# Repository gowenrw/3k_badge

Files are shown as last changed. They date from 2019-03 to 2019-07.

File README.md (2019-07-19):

# 3k_badge

3000 Society Badge Documents

## File Structure

This is the file structure of this repository

* 3k_badge_eda - Electronic Design Automation files for the badge PCB (EDA is KiCad)
  * 3000_Society_Badge_K5 - KiCad 5.x project folder for the 3000 Society Conference version of the badge
  * DC27_3000_Society_Badge_K5 - KiCad 5.x project folder for the Defcon 27 Conference version of the badge
* code - Code for programming the badge
  * 3kcode - Current python code for trinket m0 controlling the bage
* docs - Documentation created by this project related to the badge
* graphics - Artwork and other graphics created by this project for the badge
  * fonts - Truetype fonts used in the Illustrator files
* reference - Documentation pulled from other sources related to the badge components

## Badge Details

Details on the badge can be found on the website https://3kbadge.altbier.us/

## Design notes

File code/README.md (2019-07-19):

# code

Code for programming the badge

The trinket m0 can run multiple versions of Circuit Python and may come shipped with different versions loaded.

For consistency in code and deployment I have standardized on Circuit Python version 2.3.1

The trinket m0 firmware for the version we are using has been included here in file adafruit-circuitpython-trinket_m0-2.3.1.uf2

To upgrade or downgrade the trinket m0 to run Circuit Python version 2.3.1 follow these steps.

* Connect the trinket m0 to a PC via the USB port.
  * This should pop open a USB drive called CIRCUITPY that is used for adding code
* Click the small Reset button on the trinket twice.  Not like a mouse Double-click, but more like Click-pause-Click.
  * You should see the Dotstar RGB LED turn green and the Red LED turn on and a new disk drive appear called TRINKETBOOT.
* Drag the adafruit-circuitpython-trinket_m0-2.3.1.uf2 firmware file to TRINKETBOOT to copy it there.
  * The Red LED will flash then the TRINKETBOOT drive will disappear and the CIRCUITPY drive will reappear.
* That's it, the trinket is now running the new firmware for Circuit Python version 2.3.1

More information about the trinket m0 and Circuit Python can be found here https://learn.adafruit.com/adafruit-trinket-m0-circuitpython-arduino/circuitpython

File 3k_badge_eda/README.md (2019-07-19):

# 3k_badge_eda

Electronic Design Automation files for the badge PCB (EDA is KiCad)

* 3000_Society_Badge_K5 - KiCad 5.x project folder for the 3000 Society Conference version of the badge
* DC27_3000_Society_Badge_K5 - KiCad 5.x project folder for the Defcon 27 Conference version of the badge

Shitty Addon (SAO) KiCad files downloaded from here:
https://hackaday.io/project/52950-shitty-add-ons

I ended up not doing the SAO connector as planned due to time constraints.

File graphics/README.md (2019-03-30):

# graphics

Artwork and other graphics created by this project for the badge

I used Adobe Illustrator to create the vector graphics that are to be exported to KiCad.

I have included the special fonts I used in these graphics files in case they are needed to properly edit them.
These fonts are in a fonts subdirectory here.

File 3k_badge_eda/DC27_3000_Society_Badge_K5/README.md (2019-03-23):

# 3000_Society_Badge_K5

This directory contains the KiCad version 5.x project files for the 3000 Society Badge.

Here is the layout of the project directory:
* ./ - The root directory contains the main KiCad files for the project
  * <filename>.pro: project file. Holds parameters that apply to the entire project (schematic and PCB layout).
  * <filename>.sch: schematic file.
  * <filename>.kicad_pcb: the new PCB layout file.
  * <filename>.net: netlist in "Pcbnew" format
  * <filename>.bak: backup of schematic file.
  * <filename>.kicad_pcb-bak: backup of the new PCB layout file.
  * <filename>-cache.lib: a local cache copy of all the symbols used in the schematic
  * fp-lib-table: Footprint library list
  * sym-lib-table: Schematic library list
* ./lib_sh - This directory contains schematic library files
  * <filename>.lib: schematic symbols library file.
* ./lib_fp - This directory contains footprint module directories
  * <dirname>.pretty: footprint module directory
    * <filename>.mod: footprint module file
* ./3d_models - This directory contains footprint 3d model files
  * <filename>.wrl: VRML 3D model used in the 3D viewer to represent parts.
* ./gerber - This directory contains gerber formatted files for manufacturing

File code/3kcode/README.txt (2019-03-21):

Welcome to CircuitPython!
#############################

Visit the Trinket M0 product page here for more info:
                              https://adafruit.com/product/3500

#############################

The Trinket has a very tiny disk drive so we have disabled Mac OS X indexing
which could take up that valuable space.

So *please* do not remove the empty .fseventsd/no_log, .metadata_never_index
or .Trashes files!

#############################

The pre-loaded demo shows off what your Trinket M0 can do with CircuitPython:
  * The built in DotStar LED can show any color, it will swirl through the rainbow
  * Pin D0 is an analog input, the REPL will display the voltage on this pin
    (0-3.3V is the max range)
  * Pin D1 is a true analog output, you will see the voltage slowly rise
  * Pin D2 is a digital input with a pull-up, you can touch this pad to GND
    to activate the button (or wire up a tactile button or switch!)
    If you update main.py to uncomment the relevant lines, it will act as a
    mini keyboard and emulate an 'a' key-press whenever D2 is grounded.
  * Pin D3 is a capacitive input, when touched, it will turn on the red LED.
  * Pin D4 is a NeoPixel output, you can wire up a strip of NeoPixels to this
    pin (power from USB and GND). The first 16 NeoPixel will rainbow swirl

For more details on how to use CircuitPython, visit
https://adafruit.com/product/3500 and check out all the tutorials we have!

#############################
CircuitPython Quick Start:

Changing the code is as easy as editing main.py in your favorite text editor.
We recommend Atom, Notepad++, or Visual Studio Code. After the file is saved,
CircuitPython will automatically reload the latest code. Try enabling the
single-button keyboard (HINT: look for the "# optional! uncomment below..." text)

Connecting to the serial port will give you access to better error messages and
interactive CircuitPython (known as the REPL). On Windows we recommend Tera Term
or PuTTY. On Mac OSX and Linux, 'screen' can be used from a terminal.

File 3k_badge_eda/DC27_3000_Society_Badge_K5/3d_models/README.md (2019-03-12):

# 3d_models

This directory is for .STEP and .WRL model files for all footprints

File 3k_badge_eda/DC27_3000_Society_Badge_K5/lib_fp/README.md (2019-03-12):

# lib_fp

This directory is for footprints

This local library contains footprints for the components used as well as the silkscreen art.

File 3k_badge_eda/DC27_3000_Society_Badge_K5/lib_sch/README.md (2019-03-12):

# lib_sch

This directory is for schematic symbols

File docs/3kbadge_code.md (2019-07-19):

# Godzilla vs. Blade Runner Badge Code

[HOME](/) - [DETAILS](3kbadge_details.md) - [PARTS](3kbadge_components.md) - [ASSEMBLY](3kbadge_assembly.md) - [CODE](3kbadge_code.md) - [I WANT ONE!](3kbadge_i_want_one.md)

This is where you will find detailed step by step instructions on how to update the firmware and add or change code on the trinket m0 that controls the badge.

If you received your trinket m0 as part of a badge kit or with your badge then the firmware is already at the proper version and it will already have working badge code on it.
So, you need to do nothing unless you want to change the code (see modifying code section below)

If you have sourced your own trinket m0 for a PCB only badge then you will need to update the firmware to a version that has been tested to work with our badge code unless you are planning to write your own code for it.

## Get Your Trinket M0 To Work With Our Badge

The code that runs the badge was written in CircuitPython version 2.3.1 and has been tested to work on most 2.x CircuitPython firmware versions.  
It is also known that this code does not work (for some reason that we have not had time to troubleshoot) on the CircuitPython 3.x or 4.x versions that are shipping with Trinkets now.

### Updating the CircuitPython Firmware

To update the firmware is a fairly simple process.

* Connect the trinket m0 to a PC via the USB port.
  * This should pop open a USB drive called CIRCUITPY that is used for adding code
* Click the small Reset button on the trinket twice.  Not like a mouse Double-click, but more like Click-pause-Click.
  * You should see the Dotstar RGB LED turn green and the Red LED turn on and a new disk drive appear called TRINKETBOOT.
* Drag the .uf2 extension firmware file (e.g. adafruit-circuitpython-trinket_m0-2.3.1.uf2) to TRINKETBOOT to copy it there.
  * The Red LED will flash then the TRINKETBOOT drive will disappear and the CIRCUITPY drive will reappear.
* That's it, the trinket is now running the new firmware for the Circuit Python version that you copied to it.

### Updating the CircuitPython Libraries and Code

The library files and code used are firmware version dependent.  So, if you update the firmware you need to make sure that you also update any libraries and code used to that specific firmware version.
This is very easy to do.

* Connect the trinket m0 to a PC via the USB port.
  * This should pop open a USB drive called CIRCUITPY that is used for adding code
* You will see a main.py file which contains the code and a lib directory that contains the libraries
* Copy your new code and library files to this drive overwriting the existing files.
  * This is the same process you would use on any USB drive
* That's it, the trinket should start running the new code and libraries immediately.
  * If for some reason it does not simply press the Reset button once

### Using the Firmware, Libraries and Code Provided Here

If you are going to install the badge code that has been provided here then you can use the firmware and library files that have also been provided here.

* The 2.3.1 firmware is in this GitHub repositories [code directory](https://GitHub.com/gowenrw/3k_badge/tree/master/code).
* The main.py file which contains all the code for the badge in this GitHub repositories [code/3kcode directory](https://GitHub.com/gowenrw/3k_badge/tree/master/code/3kcode).
* The 2.3.1 library files used by the code are in this GitHub repositories [code/3kcode/lib directory](https://GitHub.com/gowenrw/3k_badge/tree/master/code/3kcode/lib).

### Using the Firmware and Libraries provided by Adafruit CircuitPython

If you are going to write your own badge code and use a different version of CircuitPython than what has been provided then you will need to download the Firmware and Libraries from Adafruit CircuitPython.

Find the CircuitPython firmware release you wish to use from the [Adafruit GitHub CircuitPython releases repository](https://GitHub.com/adafruit/circuitpython/releases) or from [https://circuitpython.org/downloads](https://circuitpython.org/downloads)

The proper firmware file will have a .uf2 extension and will contain trinket_m0 in the name.

Find the CircuitPython libraries that match your firmware release from the [Adafruit GitHub CircuitPython_Bundle releases repository](https://GitHub.com/adafruit/Adafruit_CircuitPython_Bundle/releases) or from [https://circuitpython.org/libraries](https://circuitpython.org/libraries)

If you are just looking to update a specific library or driver file there is a good listing of those downloads on the [CircuitPython Libraries Page](https://circuitpython.readthedocs.io/projects/bundle/en/latest/drivers.html)

## Modifying Code

The code that runs the badge is written in a version of Python called CircuitPython.

If you are new to CircuitPython then you will find this [Adafruit CircuitPython Guide](https://learn.adafruit.com/adafruit-trinket-m0-circuitpython-arduino/what-is-circuitpython) useful.

To get started changing the badge code you will need to plug the trinket m0 to a PC via the USB port.
This should pop open a USB drive called CIRCUITPY that is used for adding or modifying code.

All of the badge code is located in a file named main.py that is on the root directory of the CIRCUITPY drive.

Since this is a text file you can use any editor you like to modify the code.

Certain editors such as [GitHub's ATOM](https://atom.io/) or [Notepad++](https://notepad-plus-plus.org/) can highlight the python code syntax to make editing easier.

Adafruit has provided a [CircuitPython editor named MU](https://learn.adafruit.com/adafruit-trinket-m0-circuitpython-arduino/installing-mu-editor) that can be used to edit the code and interface with the trinket m0 serial output to display diagnostic information from commands like print.
This can be extremely helpful in troubleshooting your changes.

The trinket m0 should start executing your new code as soon as you save the main.py file.
If for some reason it does not simply press the Reset button once to force it to reload the code.

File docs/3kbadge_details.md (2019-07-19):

# Godzilla vs. Blade Runner Badge Details

[HOME](/) - [DETAILS](3kbadge_details.md) - [PARTS](3kbadge_components.md) - [ASSEMBLY](3kbadge_assembly.md) - [CODE](3kbadge_code.md) - [I WANT ONE!](3kbadge_i_want_one.md)

The badge PCB is a two layer board with through holes for THT components which include an Adafruit Trinket M0, ten Neopixel addressable LEDs (2x8mm,8x5mm), and all the resistors and capacitors to support them.
It is powered by a credit card sized USB battery bank that will be attached to the back via Velcro and have its cable feed through a hole designed into the PCB for this purpose.

The PCB also has a capacitive touch area that uses the touch capabilities of the Trinket M0.  All the exposed copper areas are wired to a single touch pin (with the exception of the central 'T' which was excluded to prevent a short with the lanyard)

It also comes with a custom printed lanyard that either has the 3000 Society logo or the DC214 and DHA logos depending on which version of the badge you have.

The PCB CAD design for the 3000 Society badge can be found here:
[3000_Society_Badge_PCB_v3.pdf](3000_Society_Badge_PCB_v3.pdf)
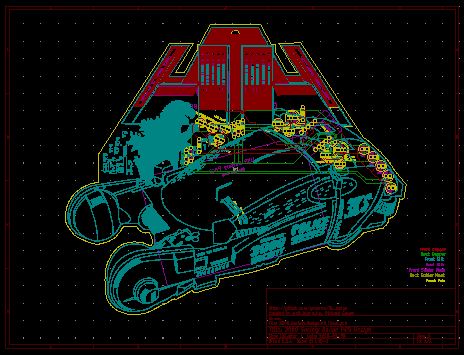
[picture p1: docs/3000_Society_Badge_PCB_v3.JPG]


The PCB CAD design for the Defcon 27 badge can be found here:
[DC27_3k_Badge_PCB_v1.pdf](DC27_3k_Badge_PCB_v1.pdf)
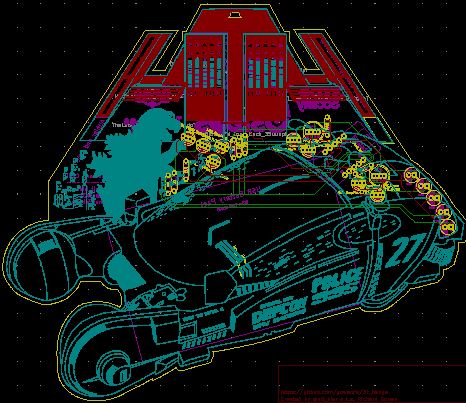
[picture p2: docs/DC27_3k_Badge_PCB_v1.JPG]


The electronic schematic for the badge can be found here (same schematic for both versions): [3000_Society_Badge_Schematic_v3.pdf](3000_Society_Badge_Schematic_v3.pdf)
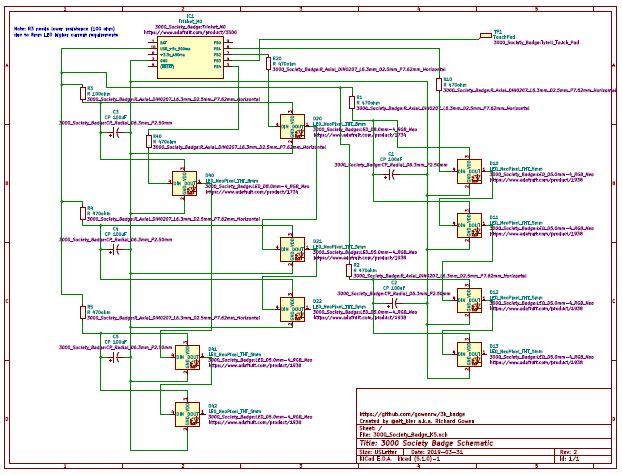
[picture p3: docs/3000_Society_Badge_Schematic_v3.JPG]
Schematic


The complete components list is available here: [3kbage_components](3kbadge_components.md)
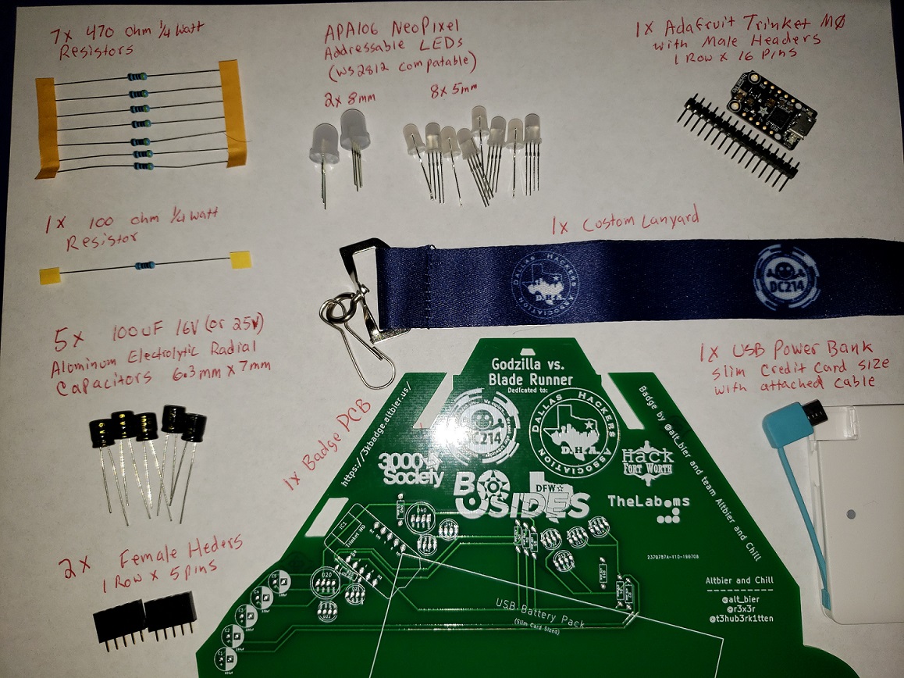
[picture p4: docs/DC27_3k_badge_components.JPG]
3kbadge_components


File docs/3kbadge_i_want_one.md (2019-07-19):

# Godzilla v. Blade Runner Badge - WANT ONE!

[HOME](/) - [DETAILS](3kbadge_details.md) - [PARTS](3kbadge_components.md) - [ASSEMBLY](3kbadge_assembly.md) - [CODE](3kbadge_code.md) - [I WANT ONE!](3kbadge_i_want_one.md)

The original version of the badge was designed for and distributed at the 3000 society conference May 31st - June 1st 2019.
Conference attendees were provided this badge at no extra change.
This was a small conference and thus there was only a small number of these badges made.
The few extras that exist will be available at the Defcon 27 conference along with the new version.

A new version of the badge was designed for the Defcon 27 conference August 8-11 2019.
These badges will be available for purchase at the conference at a location and times to be announced on Twitter.  
Follow [@alt_bier](https://twitter.com/alt_bier) and/or [#badgelife](https://twitter.com/hashtag/badgelife?src=hashtag_click) to see these announcements.

Here are the badge options that will be available at Defcon 27:

<table>
<tr>
<th width="80%">Standard Badge Options</th>
<th width="10%">Qty</th>
<th width="10%">Price Each</th>
</tr>
<tr>
<td>DC27 Godzilla vs. Blade Runner Badge PCB and Lanyard ONLY</td>
<td>80</td>
<td><b>$20</b></td>
</tr>
<tr>
<td>DC27 Godzilla vs. Blade Runner Badge Kit with all components EXCEPT the Battery</td>
<td>120</td>
<td><b>$60</b></td>
</tr>
<tr>
<td>DC27 Godzilla vs. Blade Runner Badge Fully Assembled w/ Lanyard & Battery</td>
<td>20</td>
<td><b>$120</b></td>
</tr>
</table>

<table>
<tr>
<th width="80%"><i>Rare</i> Badge Options For Collectors</th>
<th width="10%">Qty</th>
<th width="10%">Price Each</th>
</tr>
<tr>
<td>3000 Society Godzilla vs. Blade Runner Badge PCB ONLY</td>
<td>10</td>
<td><b>$40</b></td>
</tr>
<tr>
<td>DC27 Prototype Green PCB Godzilla vs. Blade Runner Badge Fully Assembled w/ Lanyard & Battery</td>
<td>4</td>
<td><b>$140</b></td>
</tr>
<tr>
<td>3000 Society Godzilla vs. Blade Runner Badge Fully Assembled w/ Lanyard & Battery</td>
<td>1</td>
<td><b>$160</b></td>
</tr>
</table>

Note: `The badge kits will NOT contain a Battery.`

We determined it would be too much hassle to try to get over 100 batteries to Vegas.
We will have just a few with us available for sale at $20 per battery.

Any micro USB battery bank will work to power the badge (the same type used to charge cell phones).
If you are planning on buying a kit consider purchasing a slim credit card size USB battery ahead of time to take with you.
They are available on Amazon and elsewhere for $15 or less.
See the [PARTS](3kbadge_components.md) page for battery details and purchase links.

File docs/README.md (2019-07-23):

# Godzilla vs. Blade Runner Badge

[HOME](/) - [DETAILS](3kbadge_details.md) - [PARTS](3kbadge_components.md) - [ASSEMBLY](3kbadge_assembly.md) - [CODE](3kbadge_code.md) - [I WANT ONE!](3kbadge_i_want_one.md)

The 3000 Society Badge was created by [@alt_bier](https://twitter.com/alt_bier) to commemorate the 10th anniversary of this awesome gaming group for their conference May 31st - June 1st 2019.
The theme for 3000 Society 2019 conference was Godzilla vs. Blade Runner which has been used as the concept for the badge.

This badge has been reworked by team **Altbier and Chill** for the [Defcon 27](https://www.defcon.org/html/defcon-27/dc-27-index.html) conference in dedication to the DFW area Hackers:

| <A HREF="http://dc214.org/">DC214</A> | <A HREF="https://www.dallashackers.com/">DHA</A> | <A HREF="https://thelab.ms/">TheLab.ms</A> |
| <A HREF="https://www.meetup.com/HackFtW/">HackFtW</A> | <A HREF="http://www.bsidesdfw.com//">BSides DFW</A> | and more... |

A portion of the proceeds will be donated to [BSides DFW](http://www.bsidesdfw.com/) to help this awesome conference.

Here is a picture of the DC27 Conference Version of the badge fully assembled (Click for Larger Image):
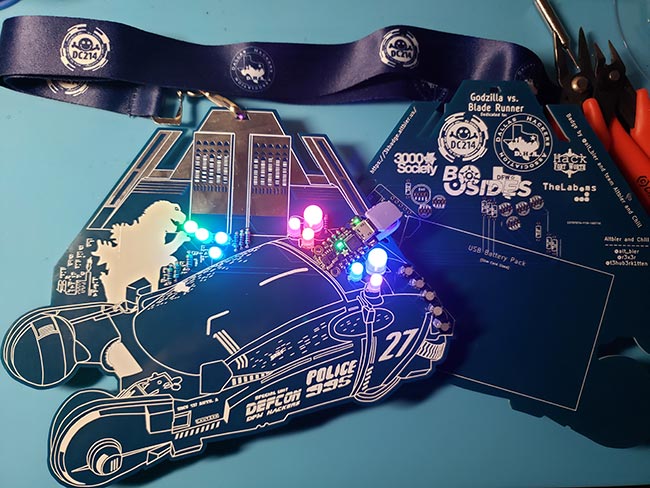
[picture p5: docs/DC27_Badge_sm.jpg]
DC27badge


Here is a picture of the 3000 Society Conference Version of the badge fully assembled:
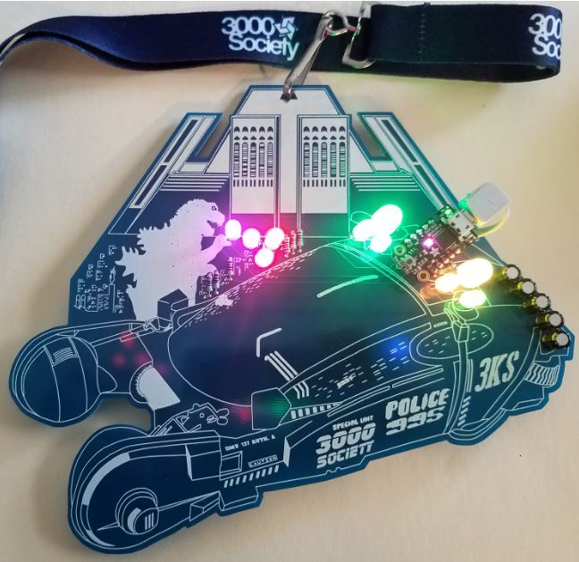
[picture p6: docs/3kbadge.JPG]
3kbadge


Since a picture alone doesn't capture the scale or the blinkey lights I put together a quick video for your enjoyment:
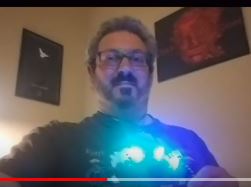
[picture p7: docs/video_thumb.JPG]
Badge Video (https://youtu.be/W0jq3bSK5AE)


## Altbier and Chill

* [@alt_bier](https://twitter.com/alt_bier)
* [@r3x3r](https://twitter.com/r3x3r)
* [@t3hub3rk1tten](https://twitter.com/t3hub3rk1tten)

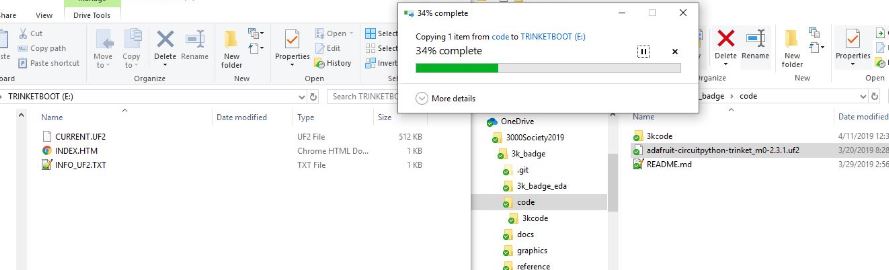
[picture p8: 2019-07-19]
docs/Code_07.JPG

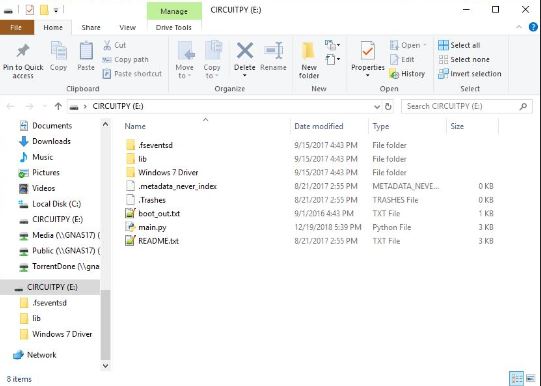
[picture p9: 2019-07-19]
docs/Code_02.JPG

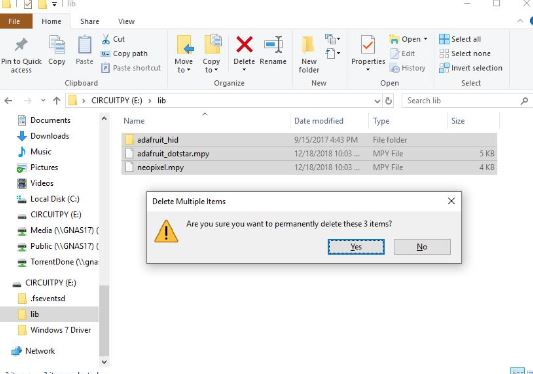
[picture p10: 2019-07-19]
docs/Code_03.JPG

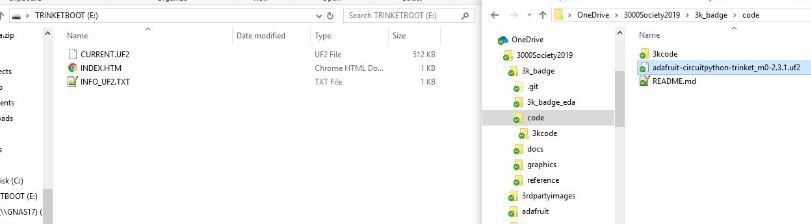
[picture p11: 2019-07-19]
docs/Code_06.JPG

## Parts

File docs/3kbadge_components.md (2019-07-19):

# Godzilla vs. Blade Runner Badge Components

[HOME](/) - [DETAILS](3kbadge_details.md) - [PARTS](3kbadge_components.md) - [ASSEMBLY](3kbadge_assembly.md) - [CODE](3kbadge_code.md) - [I WANT ONE!](3kbadge_i_want_one.md)

If you received this badge at the 3000 Society conference then you should have all the components listed below.

If you got the badge kit at Defcon 27 then you should have everything except the battery.

If you only have the PCB then this is the list of components that you will need to procure to make the badge.

Complete list of components used on the badge (with links):

* 1x Adafruit Trinket M0
    * [Adafruit Product Page](https://www.adafruit.com/product/3500)
    * [Trinket M0 Pinouts](https://learn.adafruit.com/adafruit-trinket-m0-circuitpython-arduino/pinouts)
    * [circuitpython](https://learn.adafruit.com/welcome-to-circuitpython)
* 8x NeoPixel Diffused 5mm Through-Hole LED
    * [Adafruit Product Page](https://www.adafruit.com/product/1938)
    * [Neopixel Pinouts](https://cdn-shop.adafruit.com/970x728/1938-05.jpg)
    * I used an APA106 variant, but the Adafruit WS2812 type work as well
* 2x NeoPixel Diffused 8mm Through-Hole LED
    * [Adafruit Product Page](https://www.adafruit.com/product/1734)
    * [Neopixel Pinouts](https://cdn-shop.adafruit.com/970x728/1734-04.jpg)
    * I used an APA106 variant, but the Adafruit WS2812 type work as well
* 5x 100uF 16V (or 25V) Aluminum Electrolytic Radial Capacitor 6.3 mm x 7 mm
    * [Adafruit Product Page](https://www.adafruit.com/product/2193)
    * The Adafruit capacitors above are larger than what I used but will work or at least give you an idea of what to google.
    * The original badge used 100uF 16V caps but due to a shortage 100uF 25V caps were used on later badges without issue.
* 7x 470ohm 1/4w Resistor
    * [Adafruit Product Page](https://www.adafruit.com/product/2781)
* 1x 100ohm 1/4w Resistor
    * [Sparkfun Product Page](https://www.sparkfun.com/products/14493)
    * This resistor is needed for the power line for the 8mm Neopixels.  Since they draw slightly more power than the 5mm using a 470ohm resistor was causing current drops when both 8mm LEDs were fully on.  If this does not concern you then a 470ohm resistor or some value in between can work in its place.
* 2x Male-Female 1x5pin Headers (Optional to allow easy removal of Trinket from badge)
* 1x Velcro strip 2in (Optional for battery attachment)
* 1x 2500mAh USB Power Bank - Slim Credit Card Sized
    * The badge was designed to hold a slim credit card sized USB power bank on the back that would allow the Trinket M0 to be powered via its USB micro port.
    * The model that I provided with the 3kbadges was made by [Attom Tech](https://www.attomtech.com/) and can be purchased on [their site](https://www.attomtech.com/product/attom-tech-2500mah-ultra-slim-mini-power-bank/) or on [Amazon](https://www.amazon.com/Attom-Tech-External-Emergency-Charging/dp/B076HJTNYJ) and elsewhere.
    * There are many manufacturers of these slim credit card sized USB power banks and any of them should work to power this badge as long as the physical dimensions and attributes are similar to the above. The built in charging cable and its length are of particular importance to fit the badge.

3kbadge_components

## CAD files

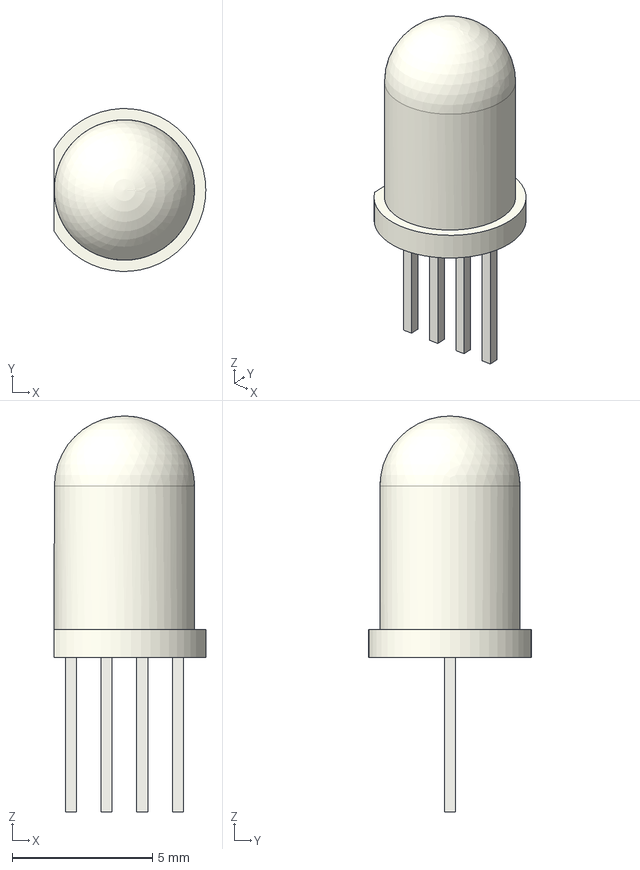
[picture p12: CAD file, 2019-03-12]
3k_badge_eda/DC27_3000_Society_Badge_K5/3d_models/LED_D5.0mm-4_RGB_Neo.step
5.40 x 5.79 x 14.1 mm

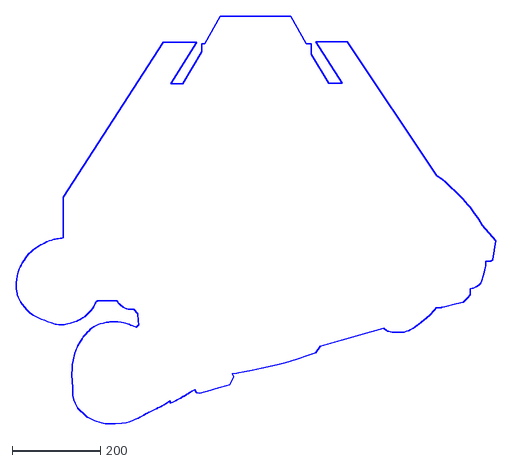
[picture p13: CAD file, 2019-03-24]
graphics/3kbadge-for-export-v4-EdgeCuts.dxf
1084.5 x 921.4

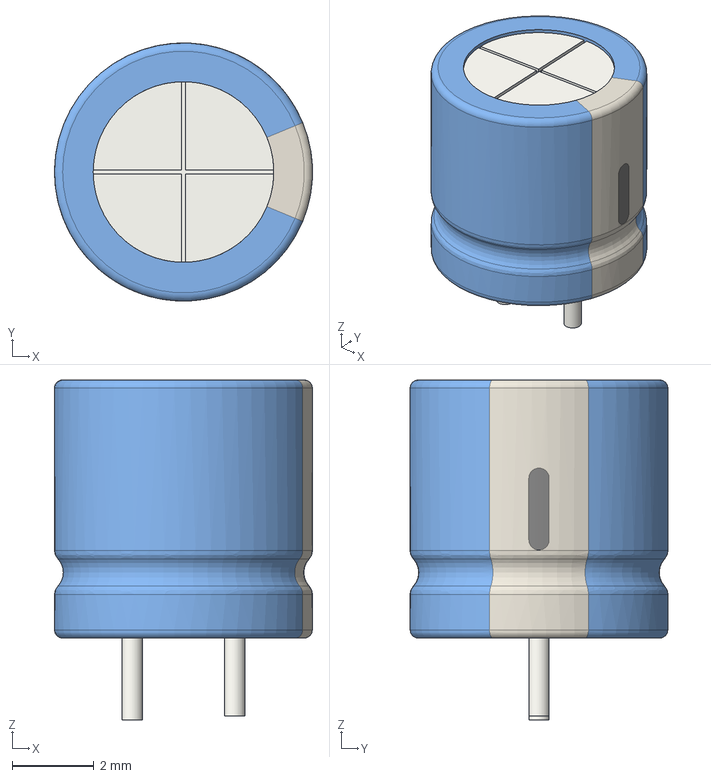
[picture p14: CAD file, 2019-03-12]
3k_badge_eda/DC27_3000_Society_Badge_K5/3d_models/CP_Radial_D6.3mm_P2.50mm.step
6.30 x 6.30 x 8.30 mm

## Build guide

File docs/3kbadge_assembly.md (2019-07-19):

# Godzilla vs. Blade Runner Badge Assembly

[HOME](/) - [DETAILS](3kbadge_details.md) - [PARTS](3kbadge_components.md) - [ASSEMBLY](3kbadge_assembly.md) - [CODE](3kbadge_code.md) - [I WANT ONE!](3kbadge_i_want_one.md)

This is where you will find detailed step by step instructions on how to assemble the badge.

## Assembly steps

<ol>

<li> Solder the Trinket M0 header pins
<ul>
<li> The Trinket comes with a single breakable 1x16pin header strip.  Break off two 5 pin sections to use. </li>
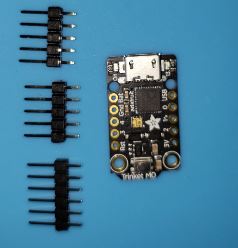
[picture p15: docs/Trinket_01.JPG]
<li>  </li>
<li> Save the left over 6 pin male header to use later </li>
<li> Place the two five pin header strips into the Trinket PCB inserting the short end into the through holes. </li>
<li> Solder these header pins on the top of the Trinket PCB </li>
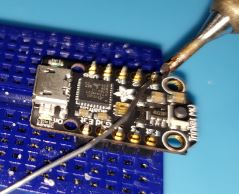
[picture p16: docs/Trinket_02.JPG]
<li>  </li>
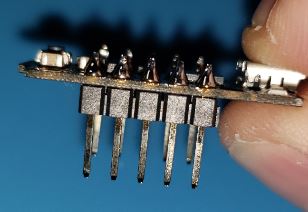
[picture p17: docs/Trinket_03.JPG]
<li>  </li>
</ul>
</li>

<li> Solder the resistors to the Badge
<ul>
<li> Place the eight resistors into the badge PCB through holes with the components on the front of the PCB. </li>
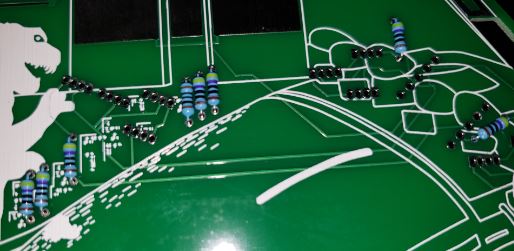
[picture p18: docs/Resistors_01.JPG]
<li>  </li>
<li> Bending the resistor legs slightly will hold them in place. </li>
<li> The direction the resistor is placed does not matter. </li>
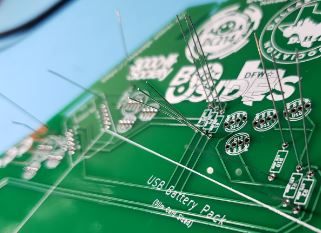
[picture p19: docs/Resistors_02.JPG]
<li>  </li>
<li> Be sure that the 100ohm resistor is in the R3 position mark on the back of the PCB. </li>
<li> Solder the resistors on the back of the PCB. </li>
<li> Cut off the resistor pins close to the back of the PCB (not too close or it will damage your solder joints) </li>
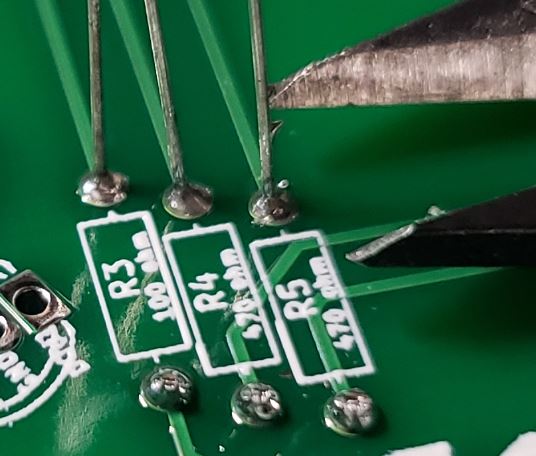
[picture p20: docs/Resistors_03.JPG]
<li>  </li>
</ul>
</li>

<li> Solder the capacitors to the Badge
<ul>
<li> Place the five capacitors into the badge PCB through holes with the components on the front of the PCB. </li>
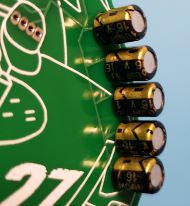
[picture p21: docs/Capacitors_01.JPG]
<li>  </li>
<li> Bending the capacitor legs slightly will hold them in place. </li>
<li> The direction the capacitors are placed is IMPORTANT. </li>
<li> The long leg is positive and the short leg where the 0 is printed on the cap is negative. </li>
<li> The long positive legs should be nearer to the outside edge of the PCB. </li>
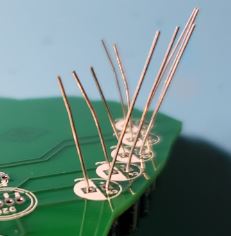
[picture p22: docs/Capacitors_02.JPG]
<li>  </li>
<li> Solder the capacitors on the back of the PCB. </li>
<li> Cut off the capacitor pins close to the back of the PCB (not too close or it will damage your solder joints) </li>
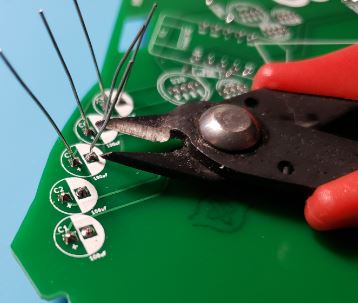
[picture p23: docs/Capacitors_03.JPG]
<li>  </li>
</ul>
</li>

<li> Solder the female headers to the Badge
<ul>
<li> Place the two 5 pin header strips male pins into the badge PCB through holes with the female headers on the front of the PCB. </li>
<li> Use the left over 6 pin male header from the Trinket to keep these headers at 90 degrees from the PCB. </li>
<li> The 6 pin male header is the perfect size to represent the trinket for spacing, just plug into the middle of each female header </li>
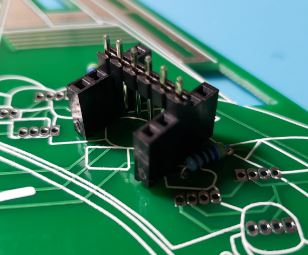
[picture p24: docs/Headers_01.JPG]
<li>  </li>
<li> Place the board down on the headers or use a bit of tape on the front to hold them in place. </li>
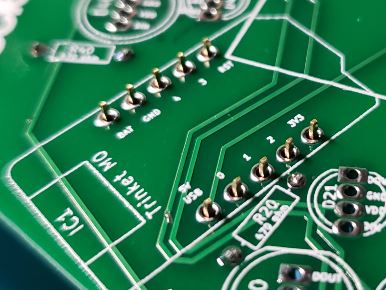
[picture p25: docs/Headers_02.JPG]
<li>  </li>
<li> Solder the headers on the back of the PCB. </li>
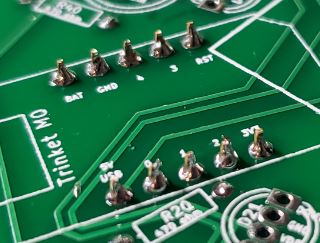
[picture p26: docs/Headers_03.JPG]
<li>  </li>
</ul>
</li>

<li> Solder the NeoPixel LEDs to the Badge
<ul>
<li> Place the ten NeoPixel LEDs into the badge PCB through holes with the components on the front of the PCB. </li>
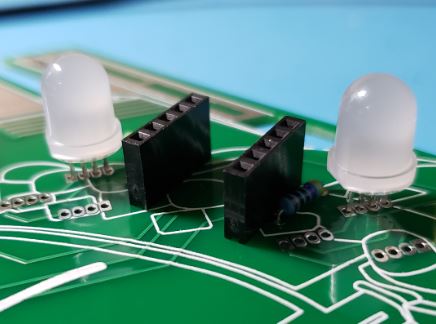
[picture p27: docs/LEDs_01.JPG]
<li>  </li>
<li> With four legs they should stay in place by friction alone. However, you can bend the LED legs slightly if needed. </li>
<li> The direction the NeoPixel LEDs are placed is IMPORTANT.  </li>
<li> On the 5mm LEDs the long leg should go in the through hole that is a rectangle instead of an oval. </li>
<li> The long leg is on the side of the LED that has a flat notch.  The back of the PCB shows where this notch should be aligned. </li>
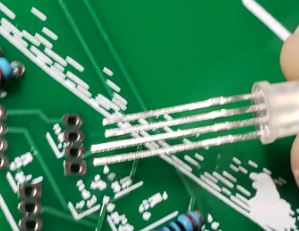
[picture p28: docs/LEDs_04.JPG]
<li>  </li>
<li> On the 8mm LEDs the long leg should go in through hole that is the oval pad next to the rectangle one. </li>
<li> On these bigger LEDs the long leg is pin 2 not pin 1 like the smaller LEDs </li>
<li> The long leg is on the side of the LED that has a flat notch.  The back of the PCB shows where this notch should be aligned. </li>
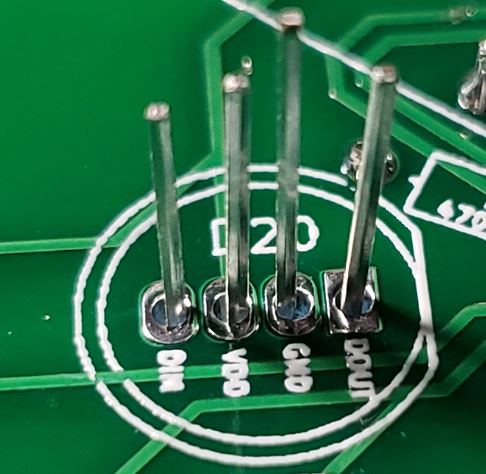
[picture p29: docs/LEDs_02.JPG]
<li>  </li>
<li> I would suggest placing and then soldering only a few LEDs at a time because they are very close together. </li>
<li> Solder the NeoPixel LEDs on the back of the PCB. </li>
<li> Cut off the LED pins close to the back of the PCB (not too close or it will damage your solder joints) </li>
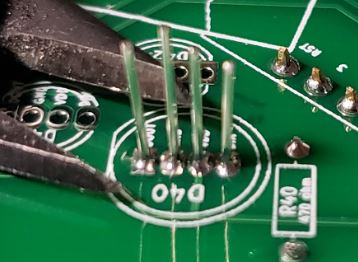
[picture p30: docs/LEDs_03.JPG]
<li>  </li>
</ul>
</li>

<li> Insert the Trinket m0 onto the badge
<ul>
<li> Place the Trinket m0 male pins into the female headers on the front of the board </li>
<li> Be sure to align the Trinket with its USB connector towards the edge of the PCB </li>
<li> Each Trinket has been preloaded with the code to control the badge.  See the code link above for details. </li>
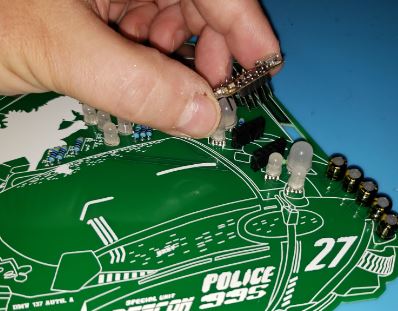
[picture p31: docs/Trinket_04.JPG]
<li>  </li>
</ul>
</li>

<li> Attach the Battery to the badge
<ul>
<li> Apply the Velcro strip to the badge PCB (Use the soft Velcro here in case you wear the badge without the battery) </li>
<li> Apply the Velcro strip to the Battery </li>
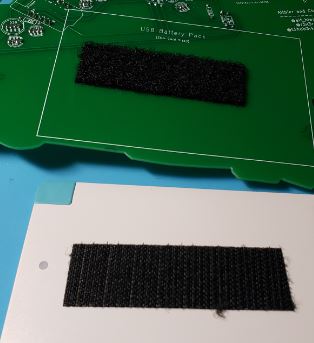
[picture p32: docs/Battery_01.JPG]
<li>  </li>
<li> Feed the Battery cable through the rectangle hole in the PCB </li>
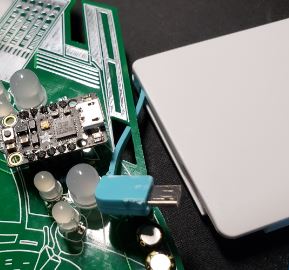
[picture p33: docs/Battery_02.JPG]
<li>  </li>
<li> Connect the Battery cable to the Trinket </li>
<li> Do this before you attach the Battery to the badge to avoid having to make readjustments </li>
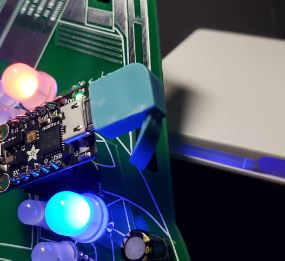
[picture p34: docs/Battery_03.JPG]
<li>  </li>
<li> Attach the Battery to the back of the badge by sticking the Velcro strips together </li>
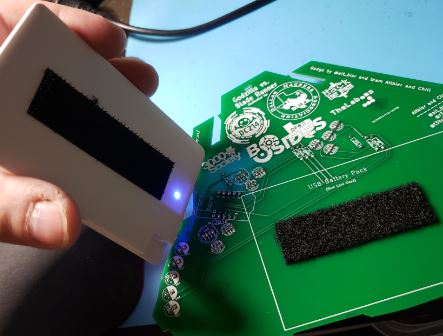
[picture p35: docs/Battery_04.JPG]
<li>  </li>
</ul>
</li>

<li> Attach the Lanyard to the badge
<ul>
<li> The Lanyard J Clip should clip into the hole at the top center of the badge PCB </li>
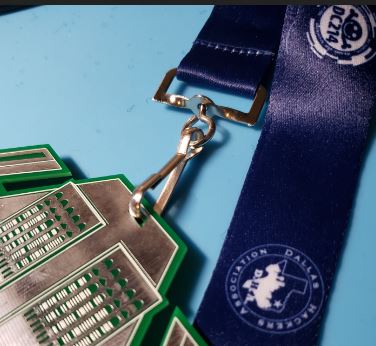
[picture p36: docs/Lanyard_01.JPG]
<li>  </li>
</ul>
</li>

<li> Rock the badge at the CON!
<ul>
<li> Touching the Tyrel building will change LED modes. </li>
<li> One of the LED modes is all off in case you need to quickly turn off without removing the battery. </li>
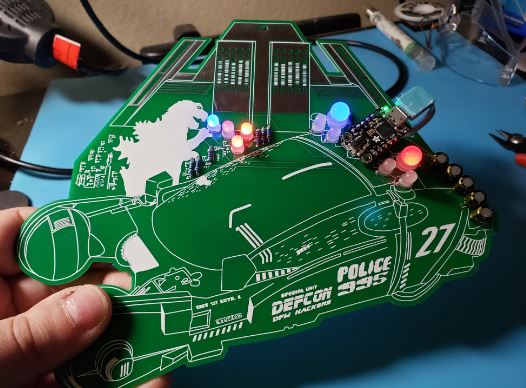
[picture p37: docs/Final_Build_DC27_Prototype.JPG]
<li>  </li>
</ul>
</li>

</ol>

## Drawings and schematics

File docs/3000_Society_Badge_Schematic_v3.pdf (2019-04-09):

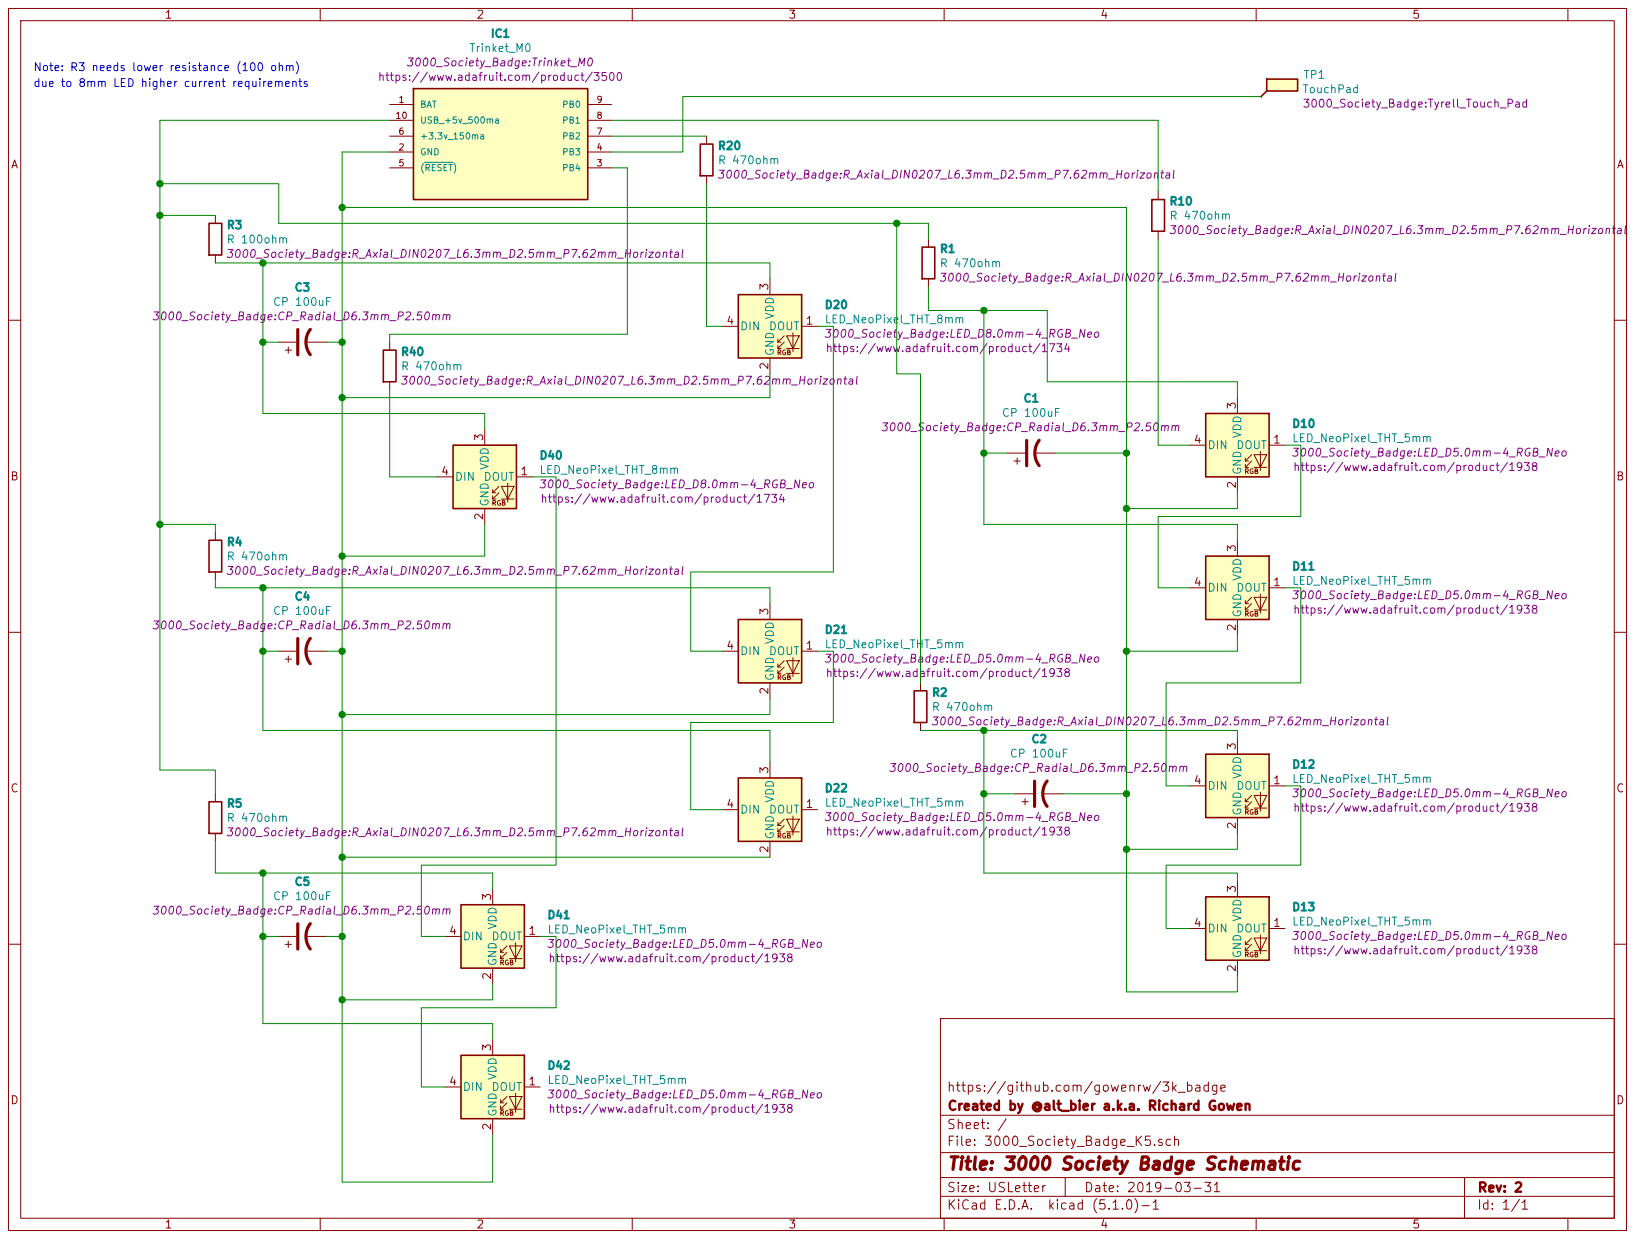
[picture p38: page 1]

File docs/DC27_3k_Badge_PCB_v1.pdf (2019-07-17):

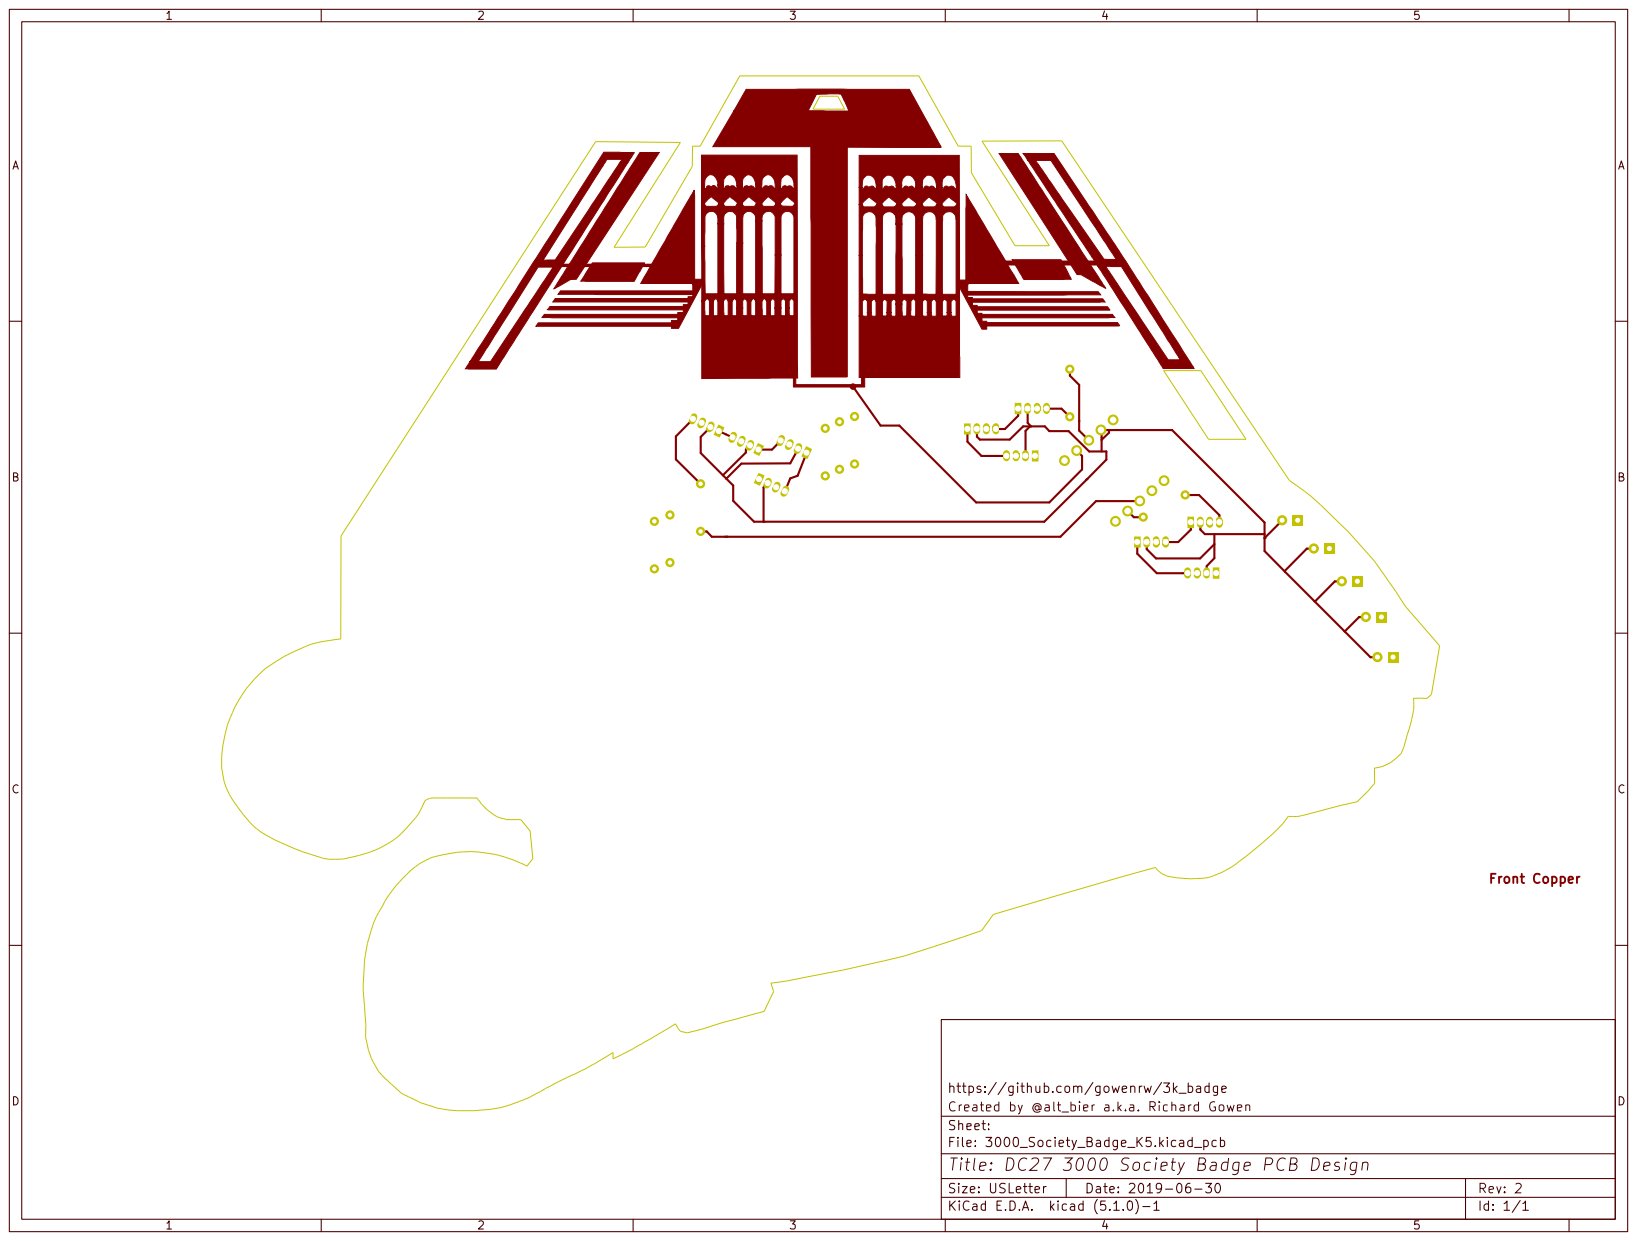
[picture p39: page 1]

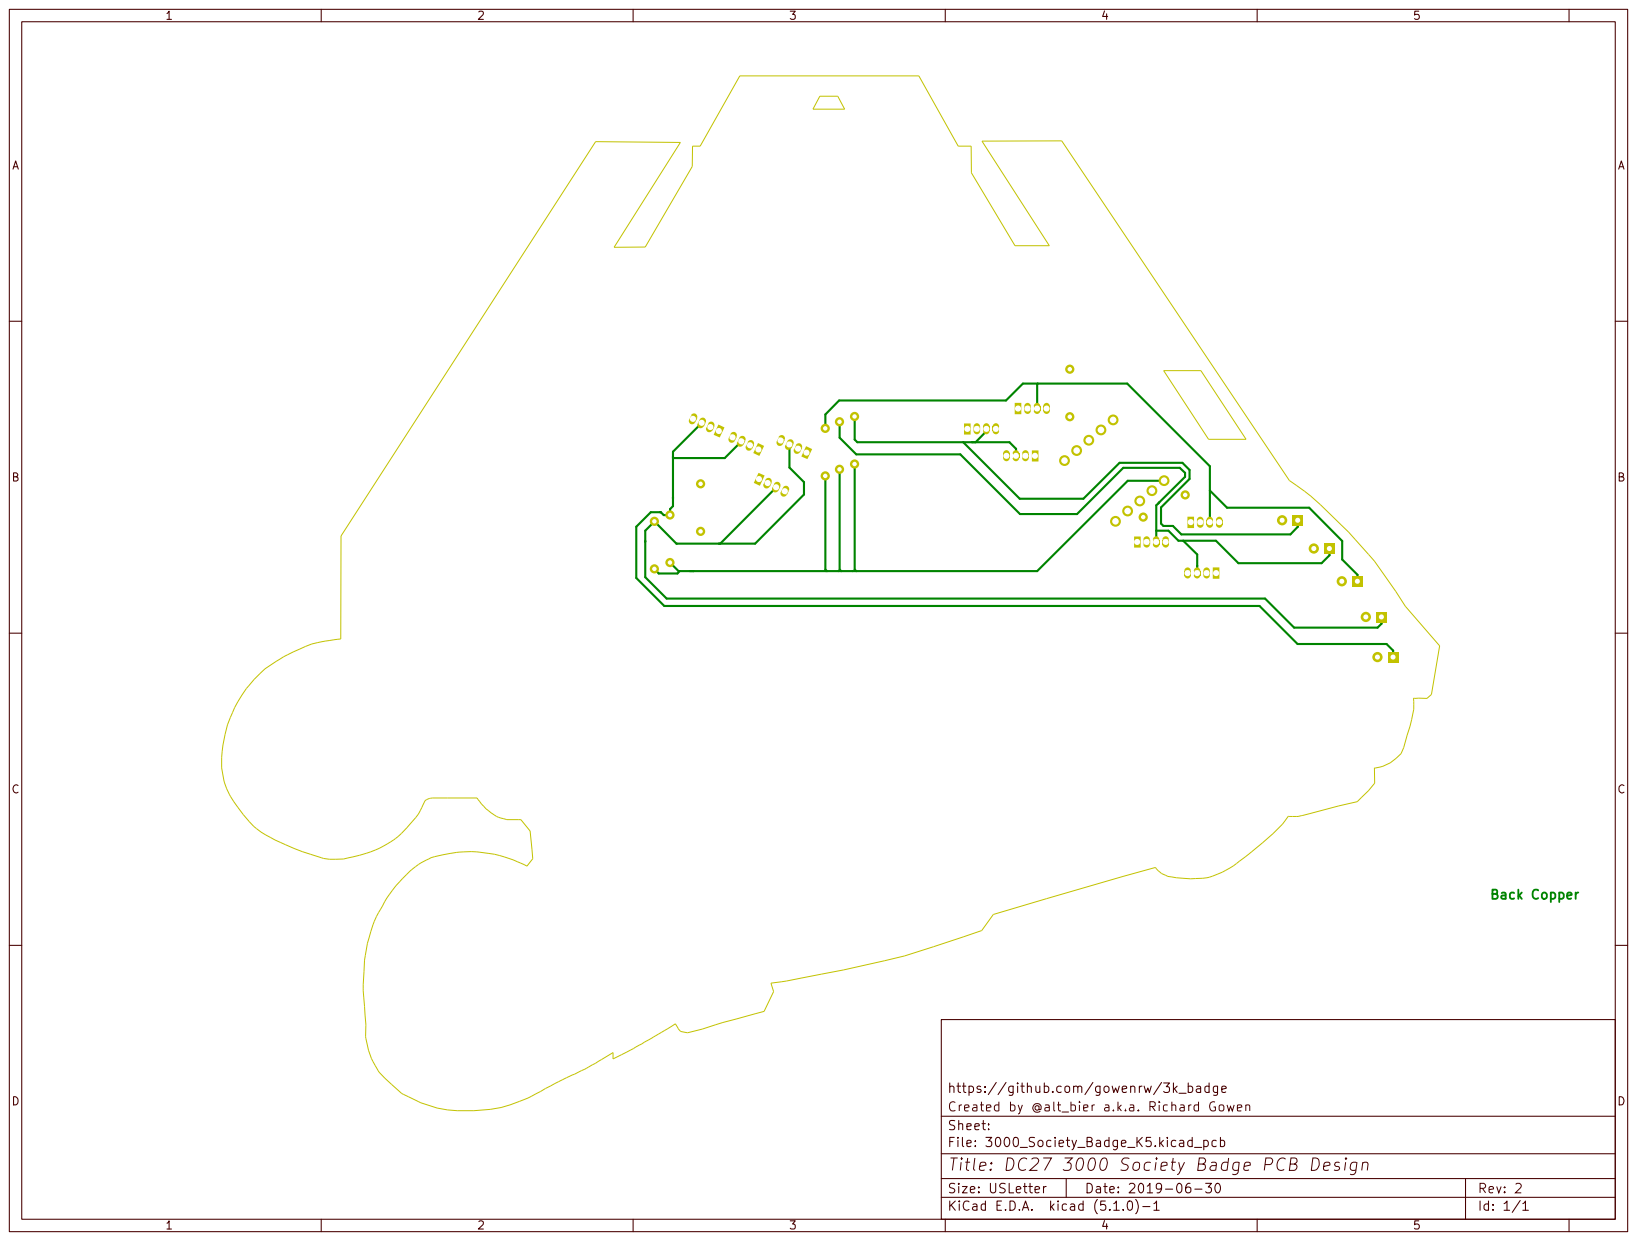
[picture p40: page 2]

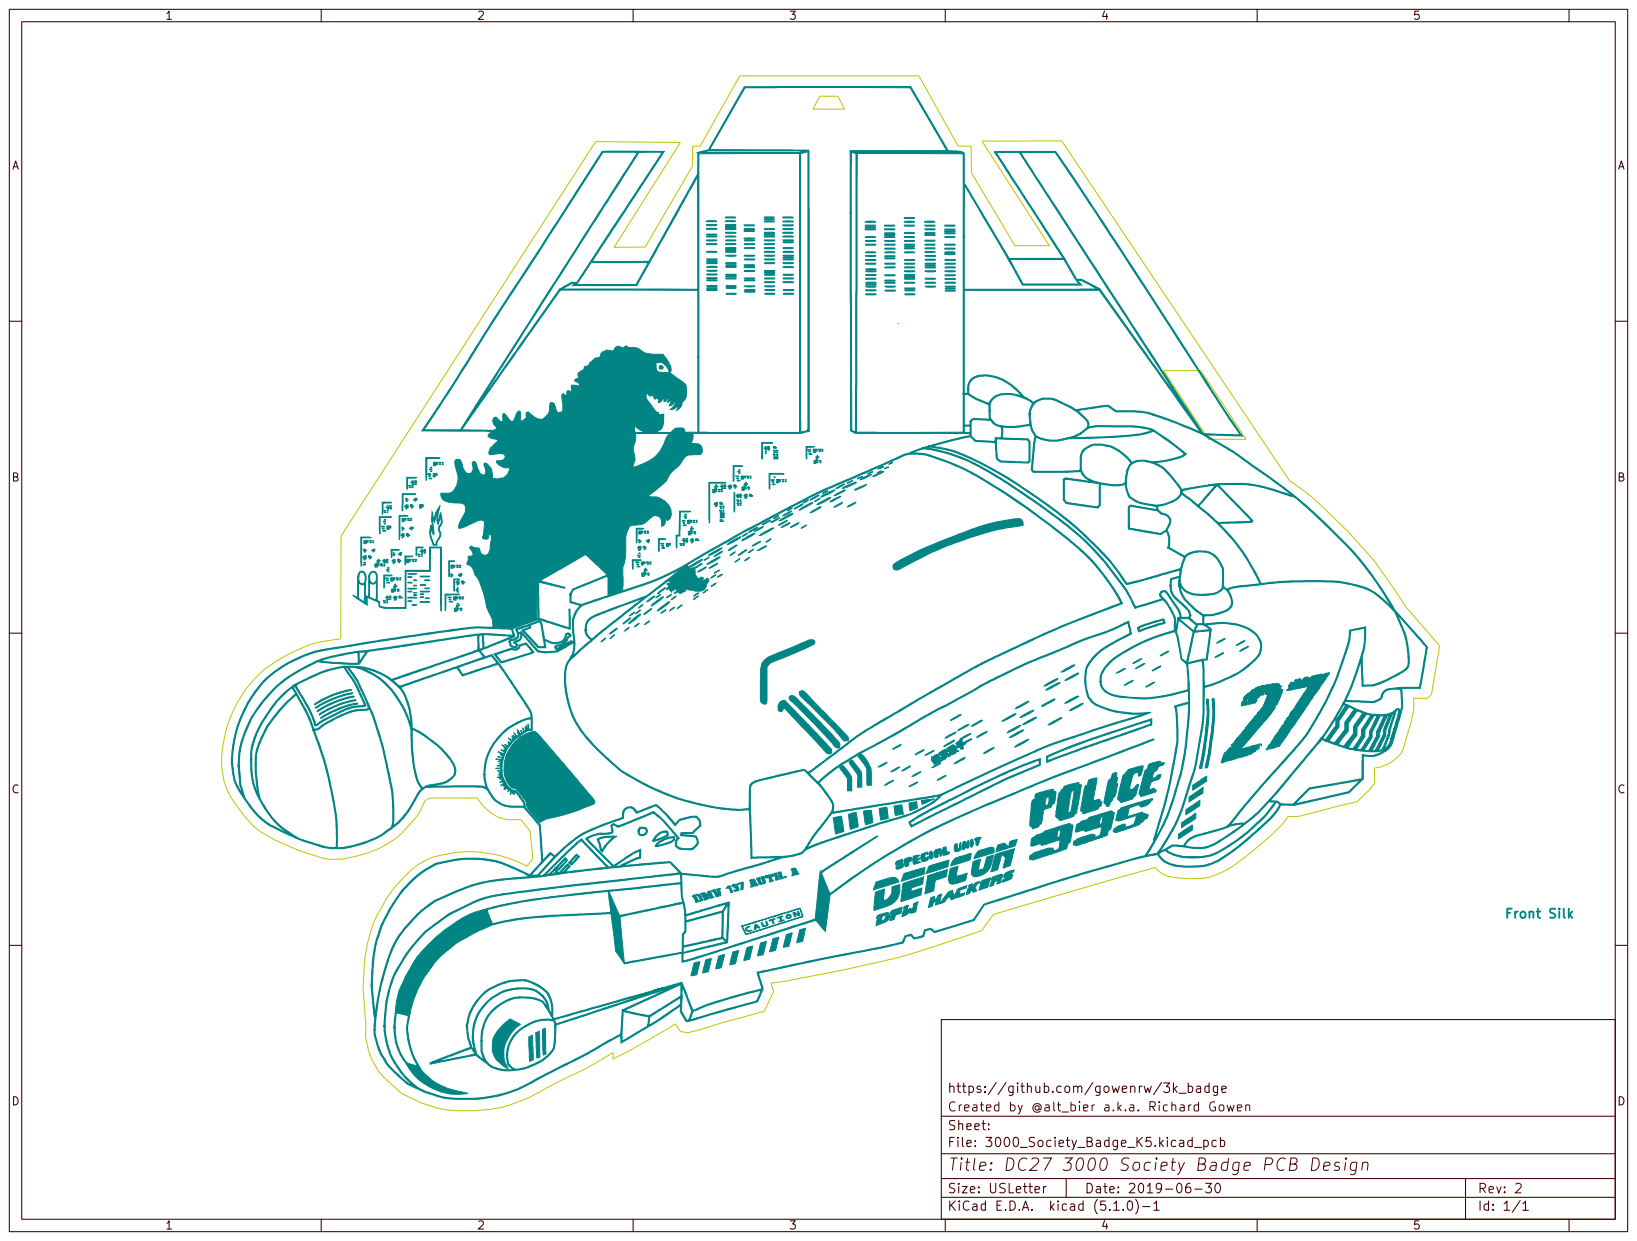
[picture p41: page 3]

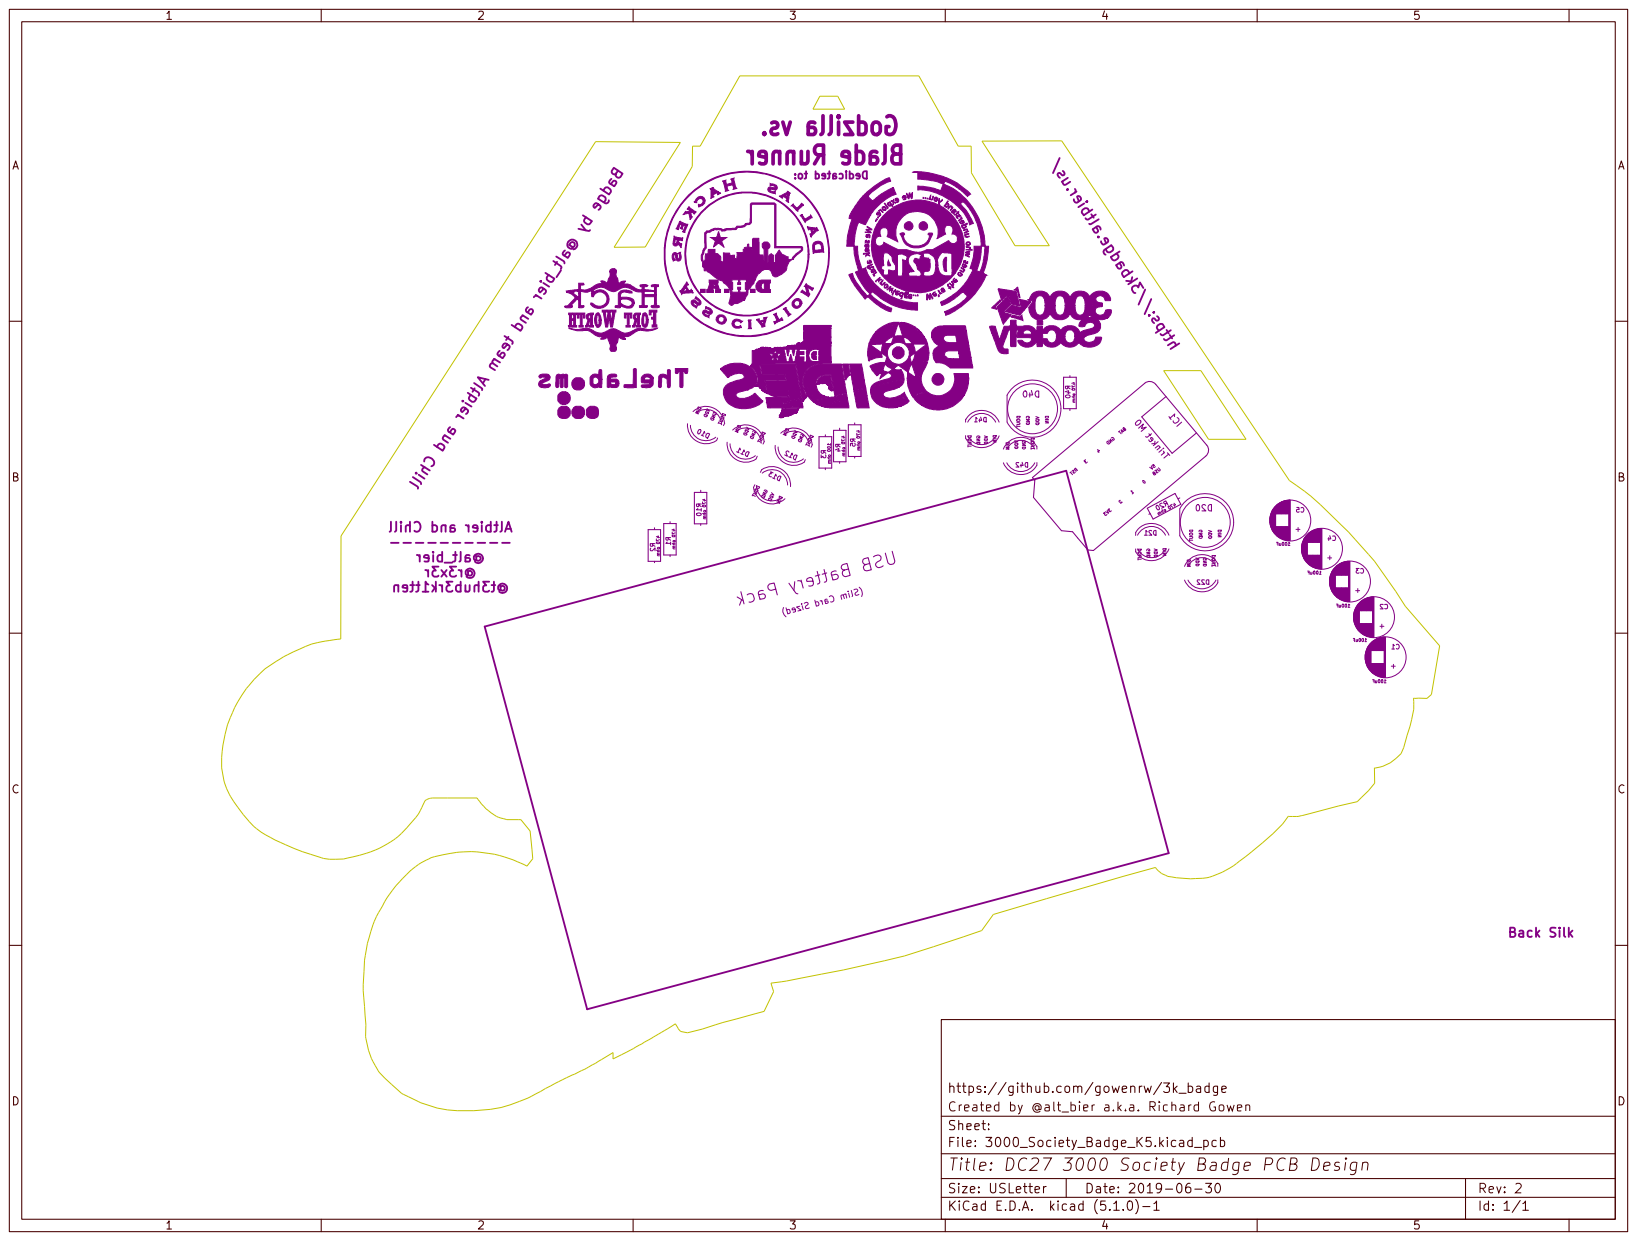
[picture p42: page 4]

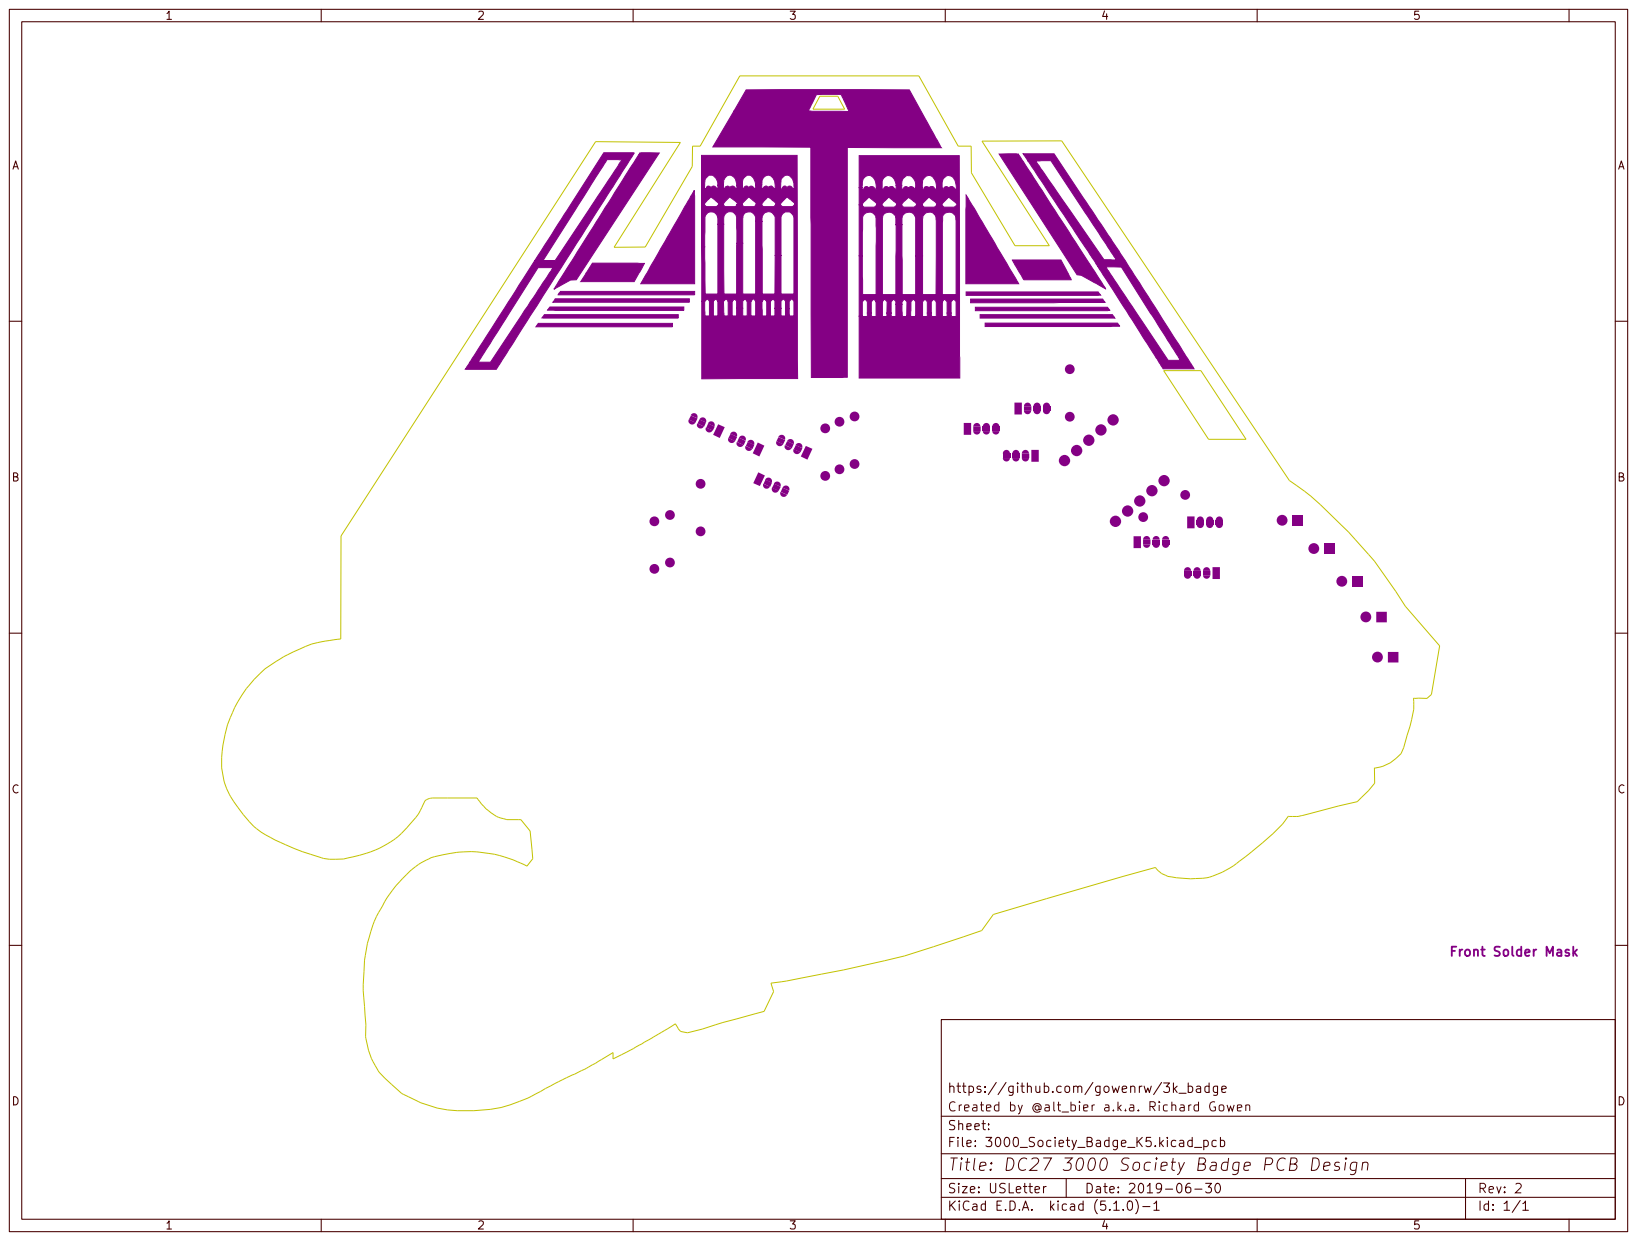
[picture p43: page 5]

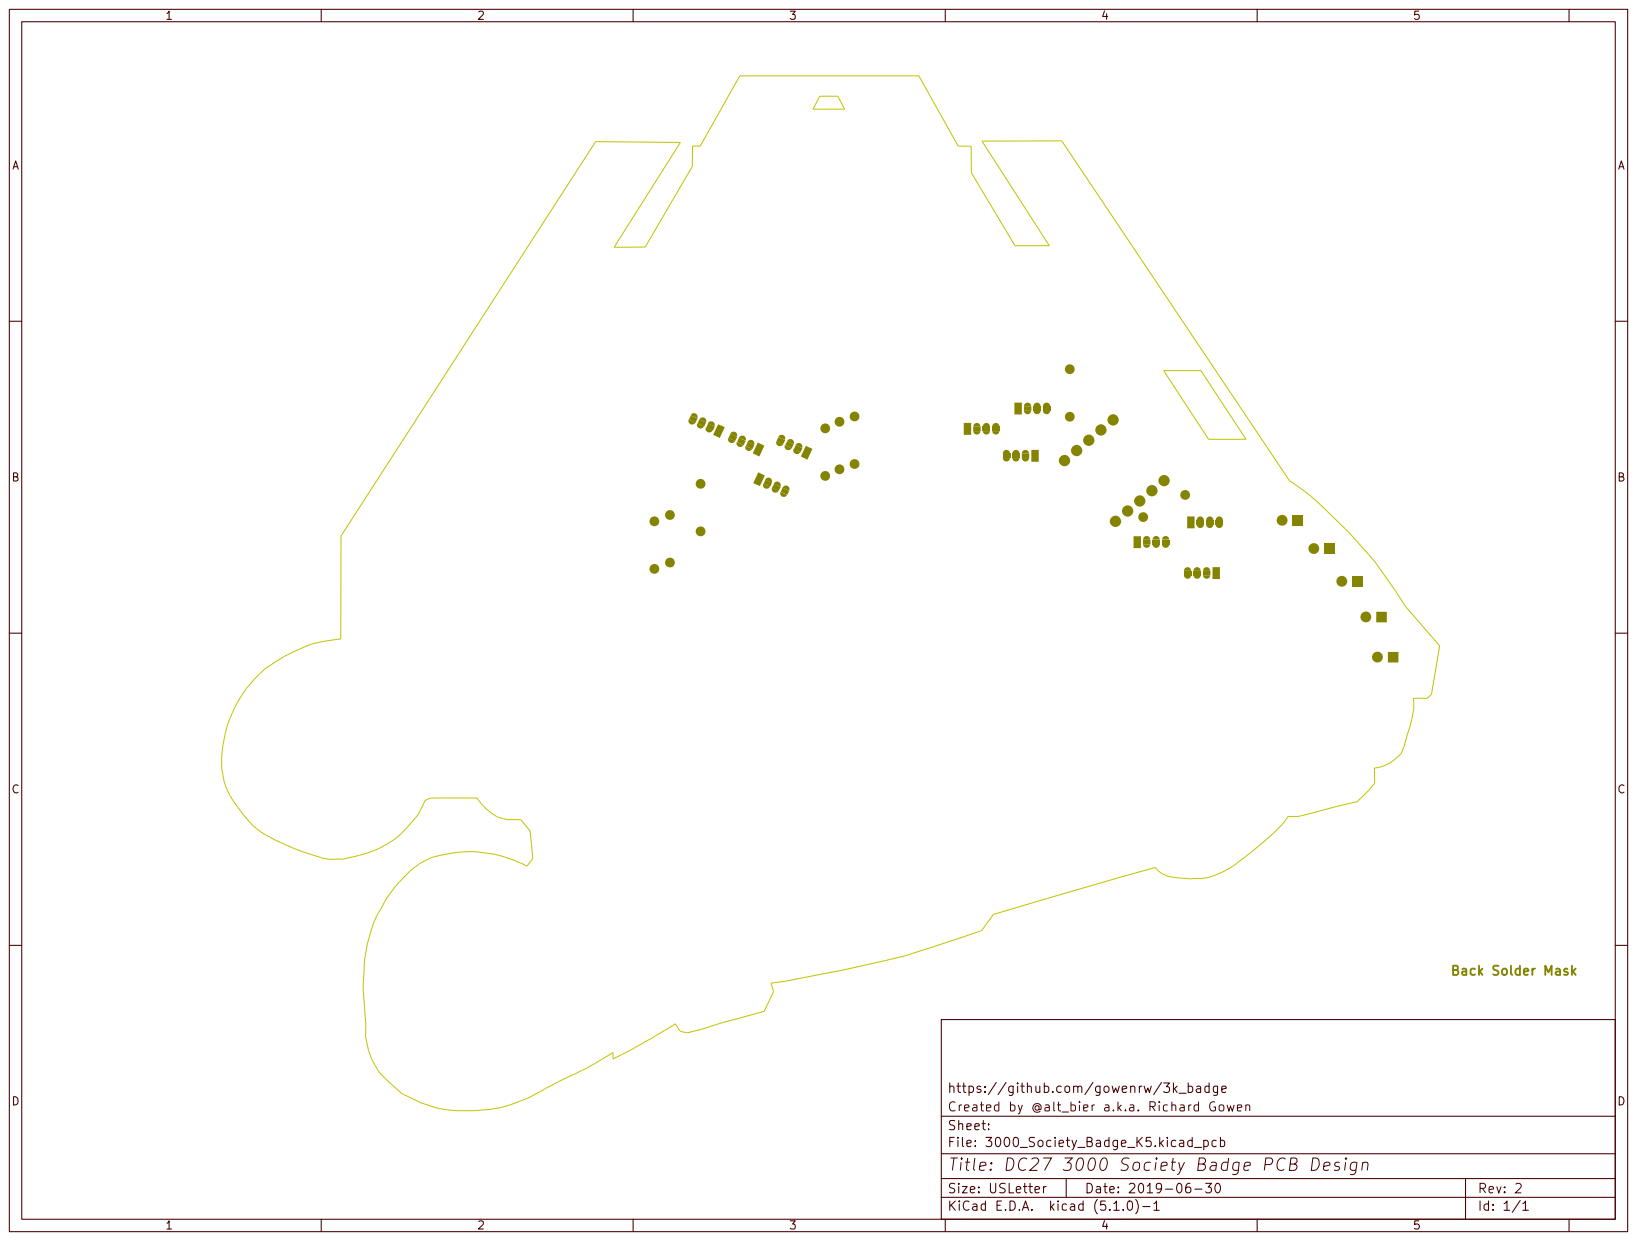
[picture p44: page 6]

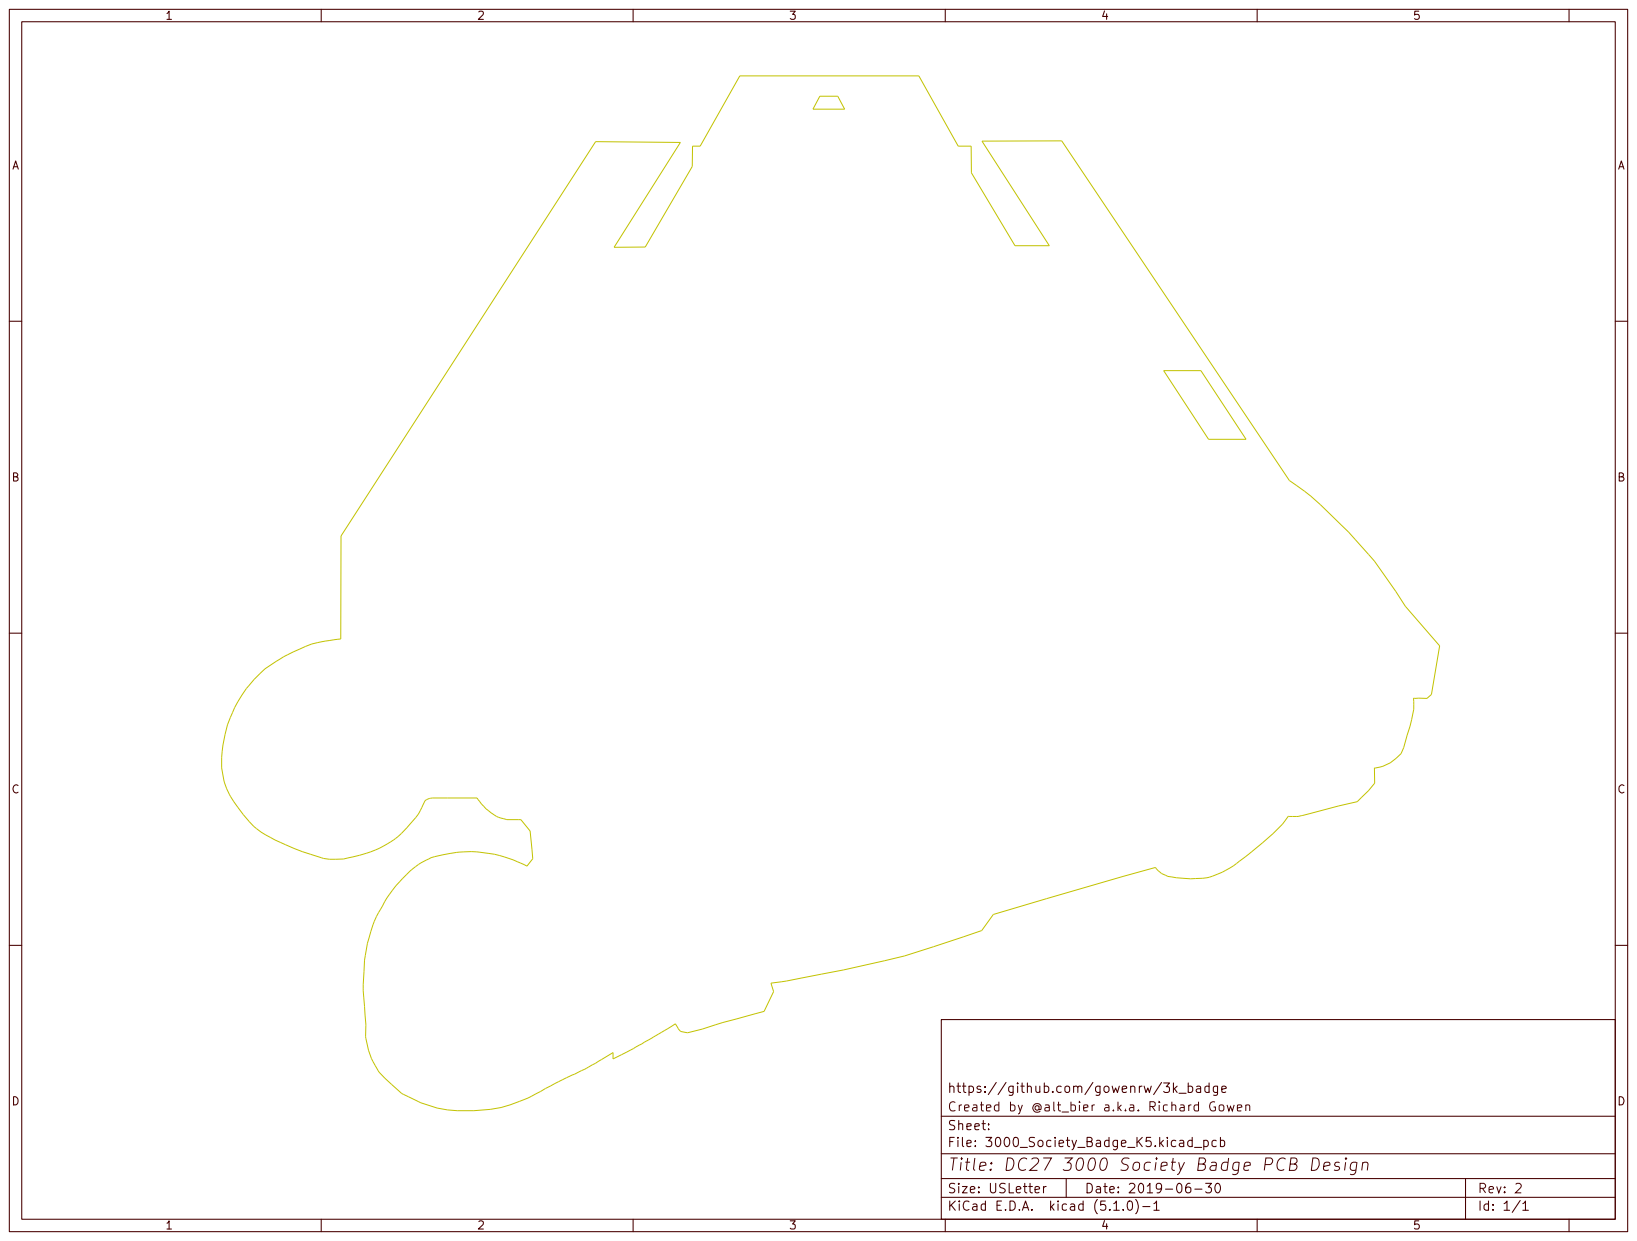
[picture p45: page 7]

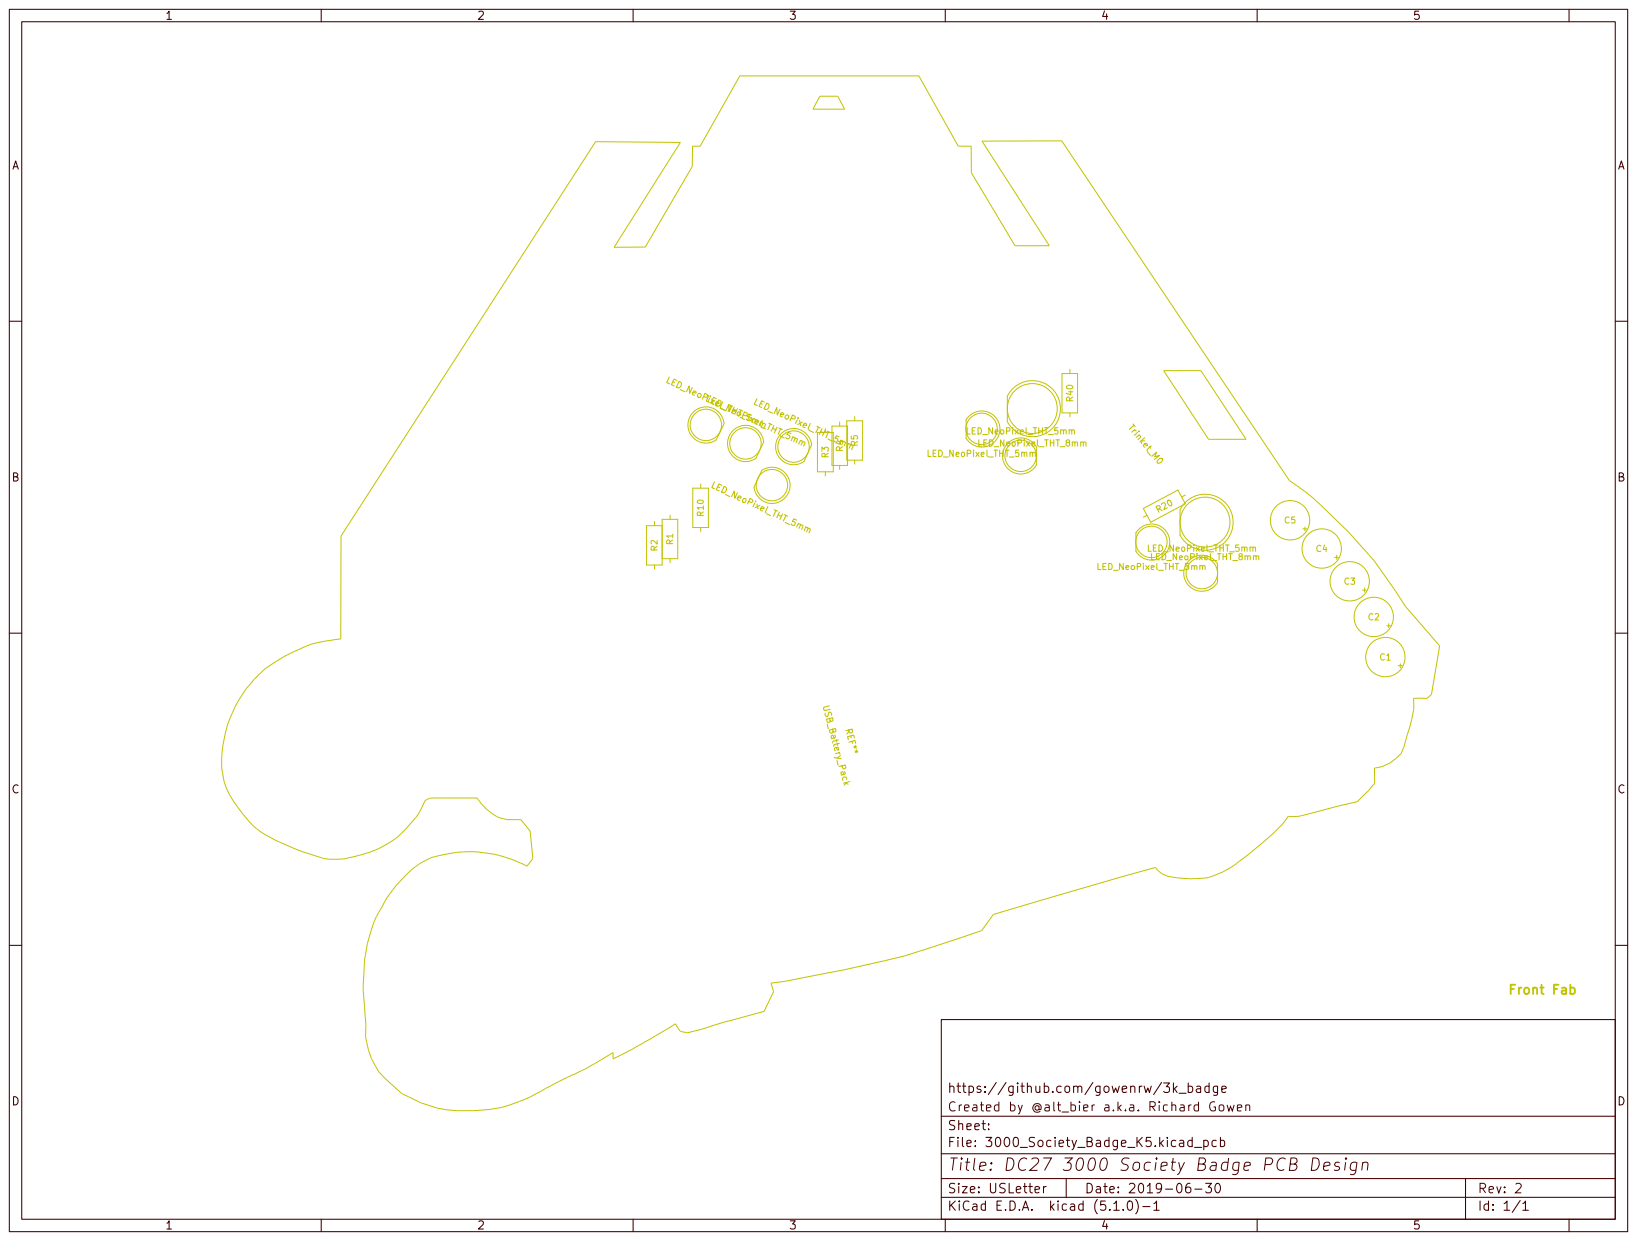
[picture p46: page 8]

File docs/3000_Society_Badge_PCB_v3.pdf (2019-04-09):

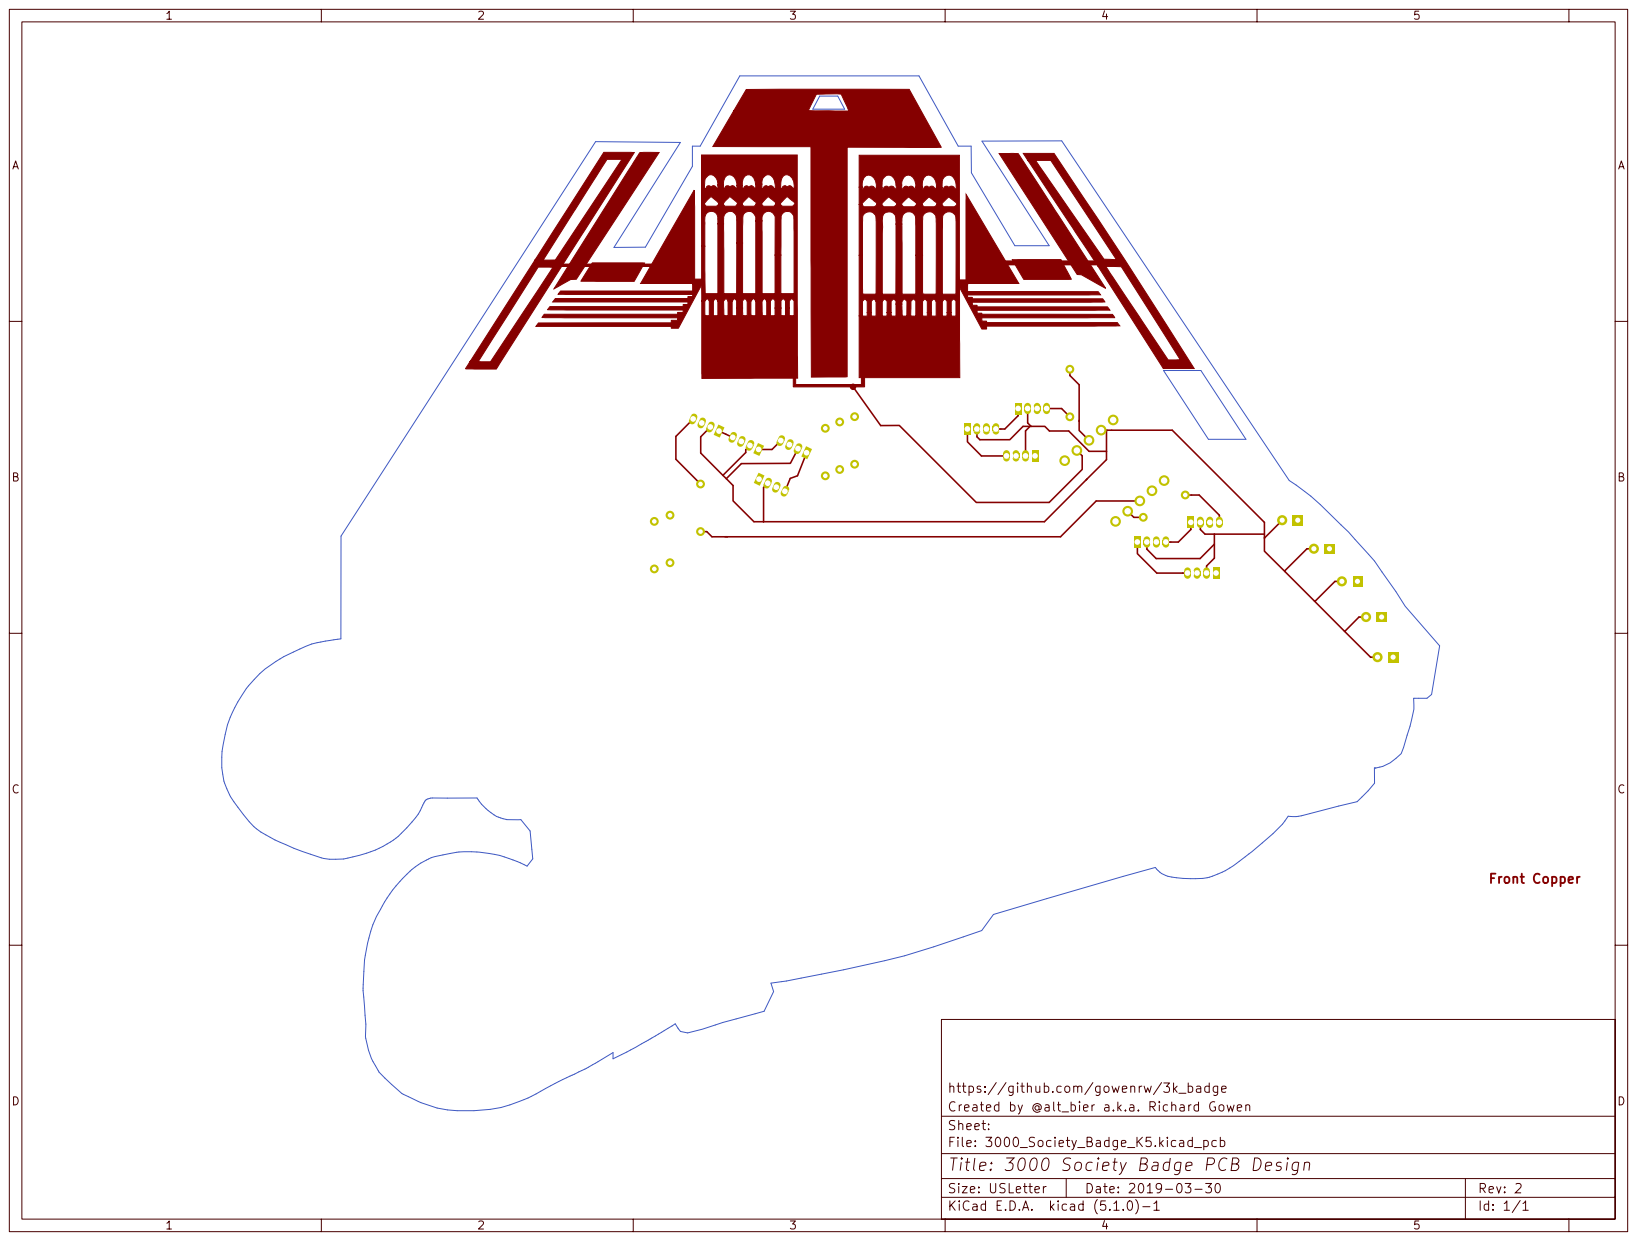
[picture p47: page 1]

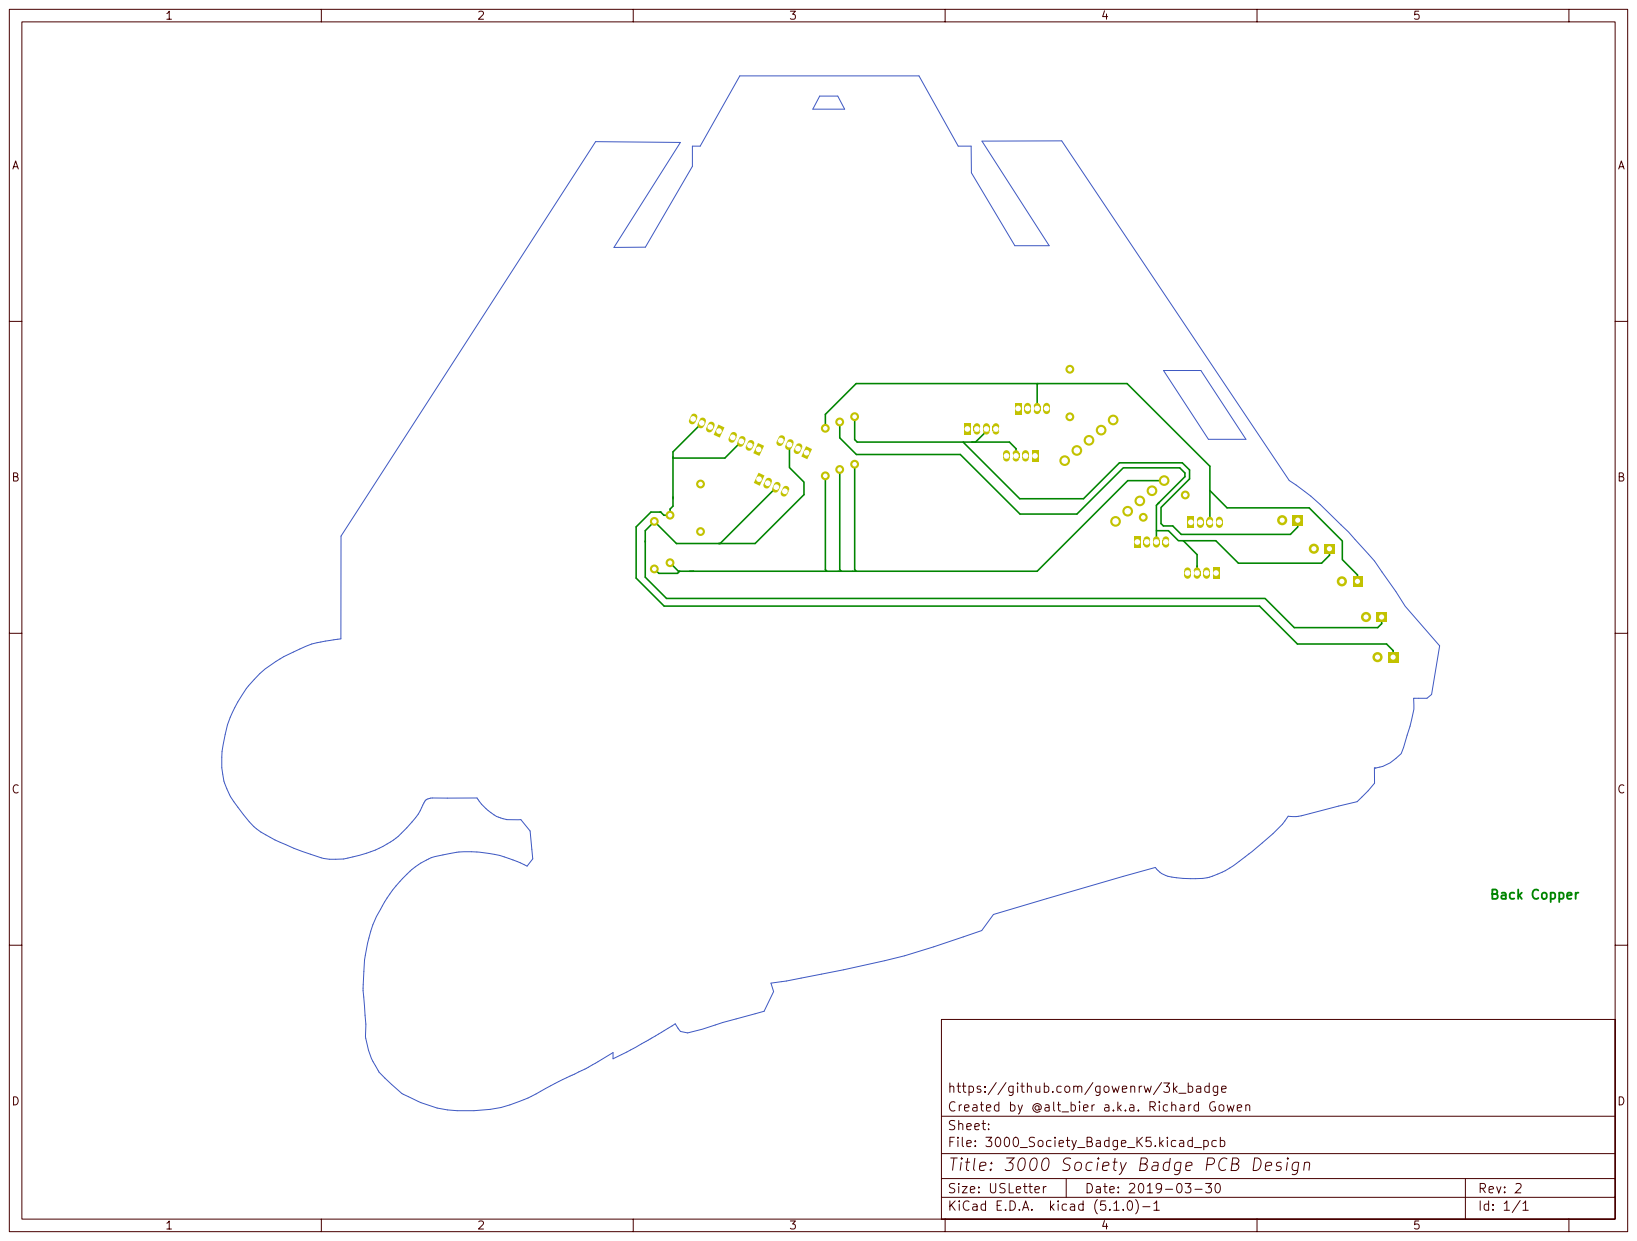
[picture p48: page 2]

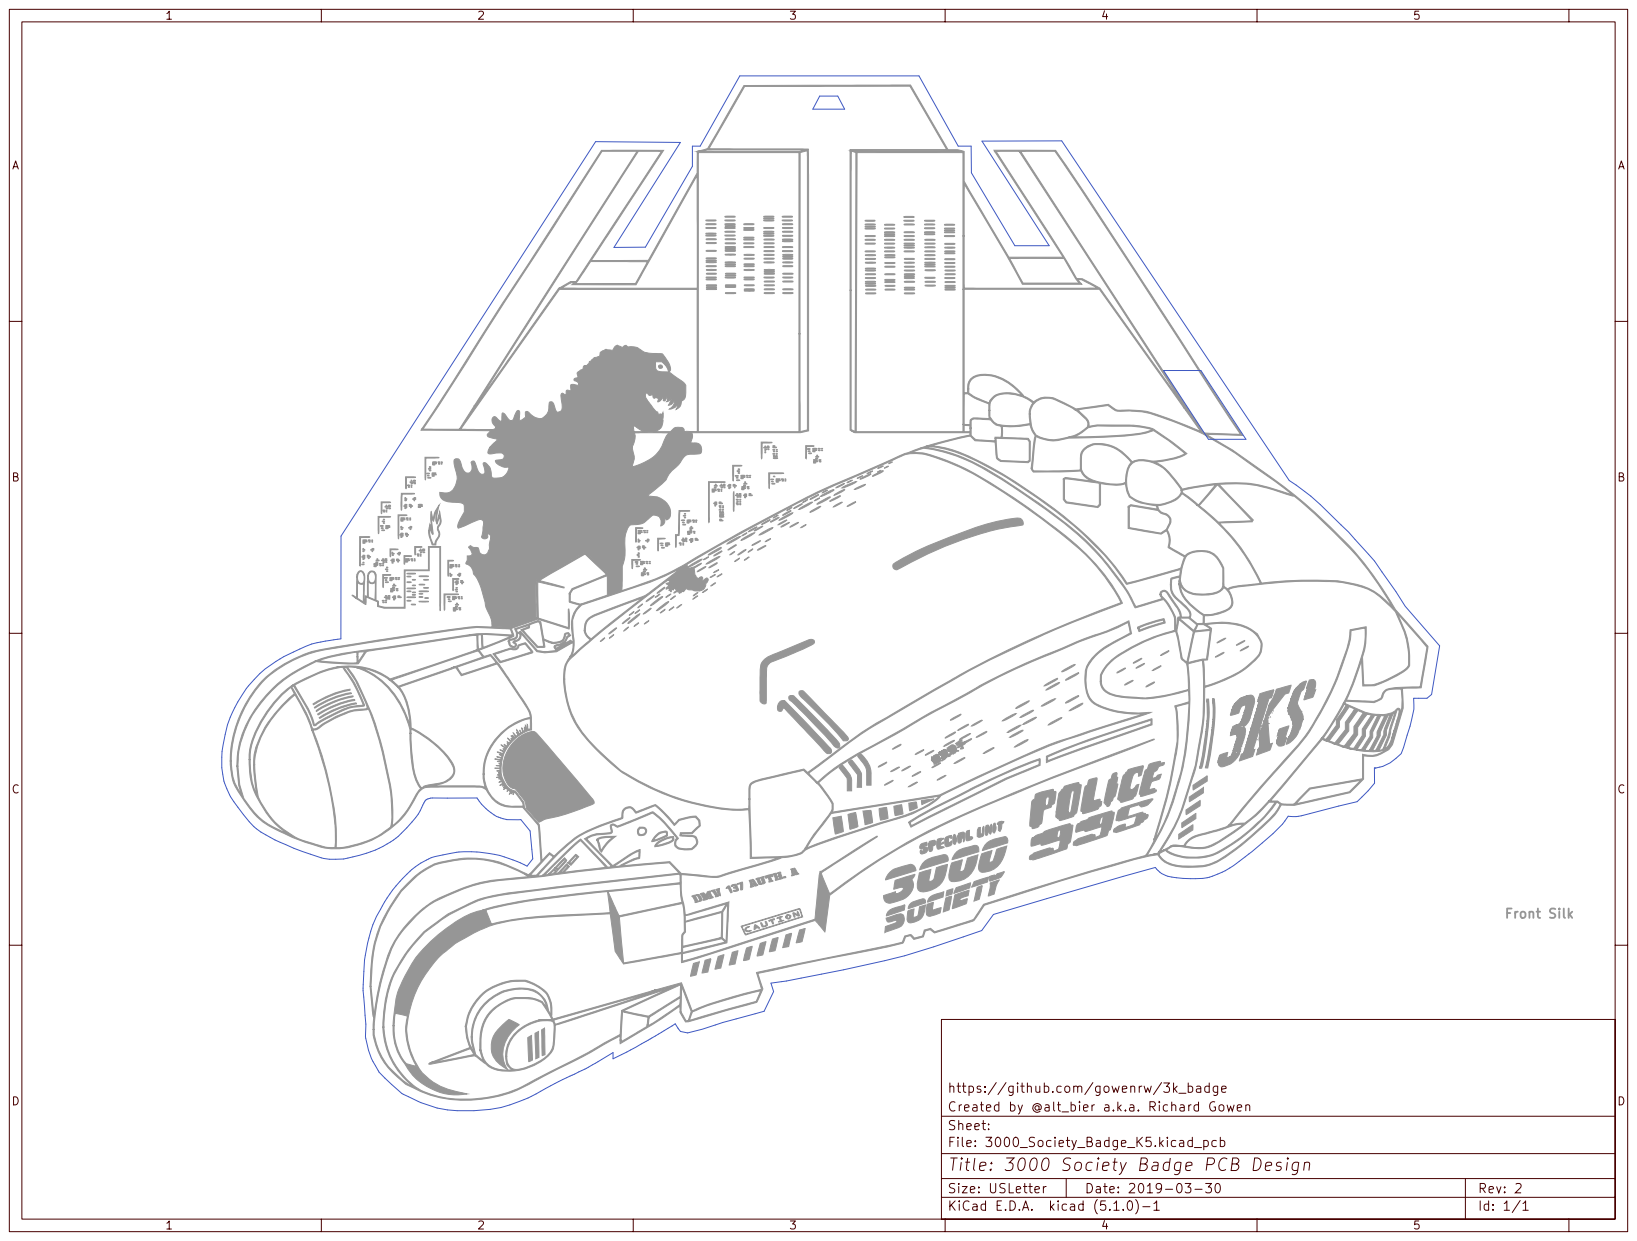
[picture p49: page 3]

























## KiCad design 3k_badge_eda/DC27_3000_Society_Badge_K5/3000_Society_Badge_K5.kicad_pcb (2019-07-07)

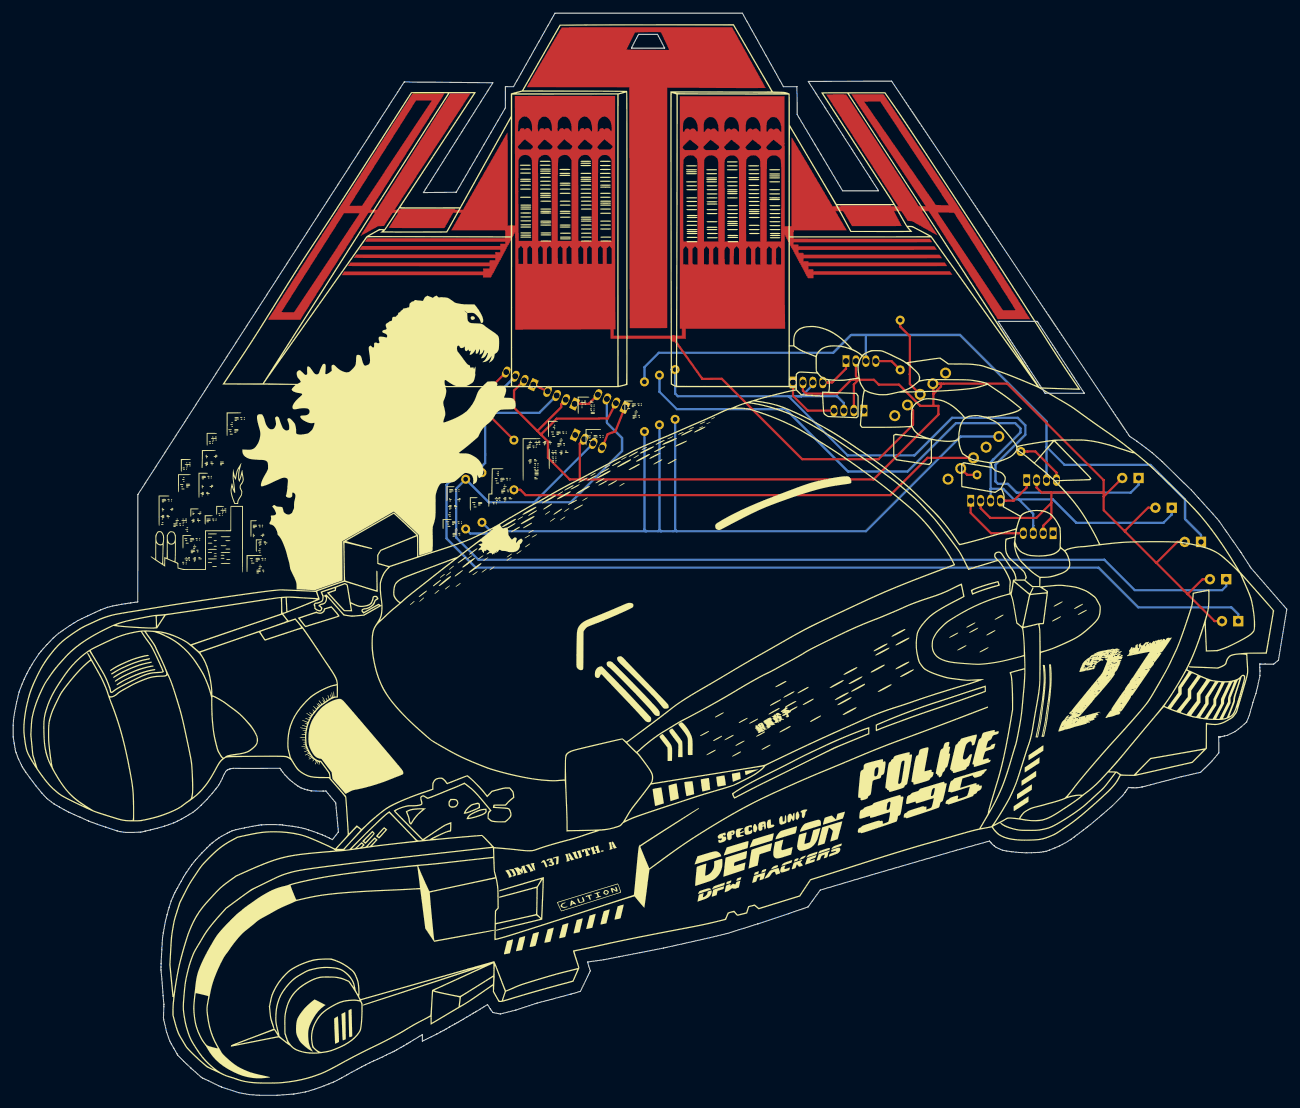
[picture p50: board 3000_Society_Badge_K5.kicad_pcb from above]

Board: 2 copper layers, 195.2 x 165.8 mm, 25 parts (0 on the bottom side), 21 nets.

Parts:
C1, C2, C3, C4, C5: 100uF; CP_Radial_D6.3mm_P2.50mm
D10, D11, D12, D13, D21, D22, D41, D42: LED_NeoPixel_THT_5mm; LED_D5.0mm-4_RGB_Neo
D20, D40: LED_NeoPixel_THT_8mm; LED_D8.0mm-4_RGB_Neo
IC1: Trinket_M0
R1, R2, R4, R5, R10, R20, R40: 470 ohm; R_Axial_DIN0207_L6.3mm_D2.5mm_P7.62mm_Horizontal
R3: 100 ohm; R_Axial_DIN0207_L6.3mm_D2.5mm_P7.62mm_Horizontal
TP1: TouchPad; Tyrell_Touch_Pad

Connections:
unnamed: C1.1, D10.3, D11.3, R1.2
unnamed: C1.2, C2.2, C3.2, C4.2, C5.2, D10.2, D11.2, D12.2, D13.2, D20.2, D21.2, D22.2, D40.2, D41.2, D42.2, IC1.2
unnamed: C2.1, D12.3, D13.3, R2.2
unnamed: C3.1, D20.3, D40.3, R3.2
unnamed: C4.1, D21.3, D22.3, R4.2
unnamed: C5.1, D41.3, D42.3, R5.2
unnamed: D10.1, D11.4
unnamed: D10.4, R10.2
unnamed: D11.1, D12.4
unnamed: D12.1, D13.4
unnamed: D20.1, D21.4
unnamed: D20.4, R20.2
unnamed: D21.1, D22.4
unnamed: D40.1, D41.4
unnamed: D40.4, R40.2
unnamed: D41.1, D42.4
unnamed: IC1.3, R40.1
unnamed: IC1.4, TP1.1
unnamed: IC1.7, R20.1
unnamed: IC1.8, R10.1
unnamed: IC1.10, R1.1, R2.1, R3.1, R4.1, R5.1

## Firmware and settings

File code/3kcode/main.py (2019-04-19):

# Test program for the 3k badge
# Note this code has been designed with CircuitPython 2.0 libraries

import board
from digitalio import DigitalInOut, Direction, Pull
import touchio
from adafruit_hid.keyboard import Keyboard
from adafruit_hid.keycode import Keycode
import adafruit_dotstar as dotstar
import time
import neopixel
import random

# One pixel connected internally!
dot = dotstar.DotStar(board.APA102_SCK, board.APA102_MOSI, 1, brightness=0.4)

# Built in red LED
led = DigitalInOut(board.D13)
led.direction = Direction.OUTPUT

# Capacitive touch on A3 (Using Analog for raw_value)
touch = touchio.TouchIn(board.A3)

# NeoPixel strip connected on D4
NUMPIXELSD4 = 3
neopixelsd4 = neopixel.NeoPixel(board.D4, NUMPIXELSD4, brightness=0.2, auto_write=False)

# NeoPixel strip connected on D2
NUMPIXELSD2 = 3
neopixelsd2 = neopixel.NeoPixel(board.D2, NUMPIXELSD2, brightness=0.2, auto_write=False)

# NeoPixel strip connected on D2
NUMPIXELSD1 = 4
neopixelsd1 = neopixel.NeoPixel(board.D1, NUMPIXELSD1, brightness=0.2, auto_write=False)

# Used if we do HID output, see below
kbd = Keyboard()

######################### FUNCTIONS ##############################

# Function to give us a nice color swirl on DOT (R,G,B)
def wheeld(pos):
    # Input a value 0 to 255 to get a color value.
    # The colours are a transition r - g - b - back to r.
    if (pos < 0) or (pos > 255):
        return (0, 0, 0)
    if pos < 85:
        return (int(255 - pos*3), int(pos*3), 0)
    elif pos < 170:
        pos -= 85
        return (0, int(255 - (pos*3)), int(pos*3))
    else:
        pos -= 170
        return (int(pos*3), 0, int(255 - pos*3))

# Function to give us a nice color swirl on NeoPixel (G,R,B)
def wheeln(pos, sft):
    if (pos + sft) > 255:
        pos = (pos + sft) - 256
    else:
        pos = (pos + sft)
    if (pos < 0) or (pos > 255):
        return (0, 0, 0)
    if pos < 85:
        return (int(pos*3), int(255 - pos*3), 0)
    elif pos < 170:
        pos -= 85
        return (int(255 - (pos*3)), 0, int(pos*3))
    else:
        pos -= 170
        return (0, int(pos*3), int(255 - pos*3))

# Function to simulate a red/blue siren on NeoPixel (G,R,B)
def siren(pos, sft):
    # pos = position, sft = shift
    if (pos + sft) > 255:
        pos = (pos + sft) - 256
    else:
        pos = (pos + sft)
    if pos < 32:
        # Red Low-High
        return (0, int(pos*8), 0)
    elif (pos > 31) and (pos < 64):
        # Red High-Low
        return (0, int(510 - (pos*8)), 0)
    elif (pos > 63) and (pos < 96):
        # Blue Low-High
        return (0, 0, int((pos*8) - 510))
    elif (pos > 95) and (pos < 128):
        # Blue High-Low
        return (0, 0, int(1020 - (pos*8)))
    elif (pos > 127) and (pos < 160):
        # Red Low-High
        return (0, int((pos*8) - 1020), 0)
    elif (pos > 159) and (pos < 192):
        # Red High-Low
        return (0, int(1530 - (pos*8)), 0)
    elif (pos > 191) and (pos < 224):
        # Blue Low-High
        return (0, 0, int((pos*8) - 1530))
    elif (pos > 223):
        # Blue High-Low
        return (0, 0, int(2040 - (pos*8)))
    else:
        return (0, 0, 0)

# Function to flash red and white on NeoPixel (G,R,B)
def flashrw(pos, sft):
    # pos = position, sft = shift
    posred = [1,2,3,4,9,10,11,12,17,18,19,20,25,26,27,28,129,130,131,132,137,138,139,140,145,146,147,148,153,154,155,156]
    posblue = [262,263]
    poswhite = [42,43,49,50,106,107,113,114,170,171,177,178,234,235,241,242]
    posyellow = [264,265]
    if (pos + sft) > 255:
        pos = (pos + sft) - 256
    else:
        pos = (pos + sft)
    if pos in posred:
        return (0, 255, 0)
    elif pos in posblue:
        return (0, 0, 255)
    elif pos in poswhite:
        return (255, 255, 255)
    elif pos in posyellow:
        return (255, 255, 0)
    else:
        return (0, 0, 0)

# Function to flash blue and yellow on NeoPixel (G,R,B)
def flashby(pos, sft):
    # pos = position, sft = shift
    posred = [262,263]
    posblue = [65,66,67,68,73,74,75,76,81,82,83,84,89,90,91,92,193,194,195,196,201,202,203,204,209,210,211,212,217,218,219,220]
    poswhite = [264,265]
    posyellow = [45,46,52,53,109,110,116,117,173,174,180,181,237,238,244,245]
    if (pos + sft) > 255:
        pos = (pos + sft) - 256
    else:
        pos = (pos + sft)
    if pos in posred:
        return (0, 255, 0)
    elif pos in posblue:
        return (0, 0, 255)
    elif pos in poswhite:
        return (255, 255, 255)
    elif pos in posyellow:
        return (255, 255, 0)
    else:
        return (0, 0, 0)

# Function to flash red and blue on NeoPixel (G,R,B) or Dot (R,G,B)
def flashrb(pos, sft, nd):
    # pos = position, sft = shift, nd = 0 neopixel 1 dot (flips red and green)
    posred = [1,2,3,4,9,10,11,12,17,18,19,20,25,26,27,28,129,130,131,132,137,138,139,140,145,146,147,148,153,154,155,156]
    posblue = [65,66,67,68,73,74,75,76,81,82,83,84,89,90,91,92,193,194,195,196,201,202,203,204,209,210,211,212,217,218,219,220]
    poswhite = [262,263]
    posyellow = [264,265]
    if (pos + sft) > 255:
        pos = (pos + sft) - 256
    else:
        pos = (pos + sft)
    if pos in posred:
        if nd == 1:
            return (255, 0, 0)
        else:
            return (0, 255, 0)
    elif pos in posblue:
        return (0, 0, 255)
    elif pos in poswhite:
        return (255, 255, 255)
    elif pos in posyellow:
        return (255, 255, 0)
    else:
        return (0, 0, 0)

# Function to flash random colors
def randcolor():
    randgr = randrd = randbl = 0
    # determine if all colors off
    if (random.randint(0,29) == 1):
        # if on then determine if each color is off and return an intensity value if on
        if (random.randint(0,1) == 1):
            randgr = random.randint(1,255)
        if (random.randint(0,1) == 1):
            randrd = random.randint(1,255)
        if (random.randint(0,1) == 1):
            randbl = random.randint(1,255)
    return (randgr, randrd, randbl)

# Function to turn all LEDs off in a neopixel string
def alloff(pixel):
    for j in range(len(pixel)):
        pixel[j] = (0, 0, 0)

######################### MAIN LOOP ##############################
mode = 0
touched = 0
i = 0
while True:
    # NeoPixels are on D1 and D2 and D4
    # NeoPixel values are in the color order (G, R, B)
    # The onboard Dot uses color order (R, G, B)

    if (mode == 0):
        # Bad boys, bad boys, whatchya gonna do?
        neopixelsd1[0] = siren(i, 16)
        neopixelsd1[1] = siren(i, 8)
        neopixelsd1[2] = siren(i, 0)
        neopixelsd1[3] = siren(i, 0)
        neopixelsd2[0] = siren(i, 0)
        neopixelsd2[1] = flashrw(i, 0)
        neopixelsd2[2] = flashby(i, 128)
        neopixelsd4[0] = siren(i, 64)
        neopixelsd4[1] = flashby(i, 0)
        neopixelsd4[2] = flashrw(i, 128)
        dot[0] = flashrb(i, 128, 1)
    elif (mode == 1):
        # Candy is dandy but liquor is quicker!
        neopixelsd1[0] = wheeln(i, 0)
        neopixelsd1[1] = wheeln(i, 16)
        neopixelsd1[2] = wheeln(i, 48)
        neopixelsd1[3] = wheeln(i, 32)
        neopixelsd2[0] = wheeln(i, 80)
        neopixelsd2[1] = wheeln(i, 64)
        neopixelsd2[2] = wheeln(i, 96)
        neopixelsd4[0] = wheeln(i, 128)
        neopixelsd4[1] = wheeln(i, 112)
        neopixelsd4[2] = wheeln(i, 144)
        dot[0] = wheeld(i)
    elif (mode == 2):
        # My God, it's full of stars!
        neopixelsd1[0] = randcolor()
        neopixelsd1[1] = randcolor()
        neopixelsd1[2] = randcolor()
        neopixelsd1[3] = randcolor()
        neopixelsd2[0] = randcolor()
        neopixelsd2[1] = randcolor()
        neopixelsd2[2] = randcolor()
        neopixelsd4[0] = randcolor()
        neopixelsd4[1] = randcolor()
        neopixelsd4[2] = randcolor()
        dot[0] = randcolor()
    else:
        # All Off
        alloff(neopixelsd1)
        alloff(neopixelsd2)
        alloff(neopixelsd4)
        dot[0] = (0, 0, 0)

    # Show the neopixel values defined above
    neopixelsd1.show()
    neopixelsd2.show()
    neopixelsd4.show()

    # use A3 as capacitive touch to turn on internal LED and change mode
    # note: must use analog raw_value to prevent false positive from back of board touches
    if touch.raw_value > 3500:
        print("A3 touched! Changing mode. Touch Value: ", touch.raw_value)
        touched = 1
        led.value = touch.value
    else:
        led.value = 0
    #print(touch.raw_value)

    i = (i+1) % 256
    # print (i)

    if ((i == 63) | (i == 127) | (i == 191) | (i >= 255)) and (touched == 1):
        mode = (mode+1)
        touched = 0
        i = 0
        if (mode > 3):
            mode = 0

    # time.sleep(0.001) # make bigger to slow down
    # print("Loop Complete")

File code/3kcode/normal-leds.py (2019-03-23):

# Test program for the 3k badge
# Note this code has been designed with CircuitPython 2.0 libraries

import board
from digitalio import DigitalInOut, Direction, Pull
import touchio
from adafruit_hid.keyboard import Keyboard
from adafruit_hid.keycode import Keycode
import adafruit_dotstar as dotstar
import time

# One pixel connected internally!
dot = dotstar.DotStar(board.APA102_SCK, board.APA102_MOSI, 1, brightness=0.4)

# Built in red LED
led = DigitalInOut(board.D13)
led.direction = Direction.OUTPUT

# My new D0 and D1 defs
ledrd = DigitalInOut(board.D0)
ledbl = DigitalInOut(board.D1)
ledwt = DigitalInOut(board.D2)
ledyl = DigitalInOut(board.D4)
ledrd.direction = Direction.OUTPUT
ledbl.direction = Direction.OUTPUT
ledwt.direction = Direction.OUTPUT
ledyl.direction = Direction.OUTPUT

# Capacitive touch on D3
touch = touchio.TouchIn(board.D3)

# Used if we do HID output, see below
kbd = Keyboard()

######################### HELPERS ##############################

def alloff():
    ledrd.value = False
    ledbl.value = False
    ledwt.value = False
    ledyl.value = False
    dot[0] = (0,0,0)

def redon():
    ledrd.value = True
    dot[0] = (255,0,0)

def blueon():
    ledbl.value = True
    dot[0] = (0,0,255)

def whiteon():
    ledwt.value = True
    dot[0] = (0,0,0)

def yellowon():
    ledyl.value = True
    dot[0] = (255,255,0)

def modeone():
    # ---- RED FLASH ----
    redon()
    time.sleep(0.05)
    alloff()
    time.sleep(0.05)
    redon()
    time.sleep(0.05)
    alloff()
    time.sleep(0.05)
    redon()
    time.sleep(0.05)
    alloff()
    time.sleep(0.05)
    redon()
    time.sleep(0.05)
    alloff()
    time.sleep(0.05)
    # ---- WHITE / YELLOW FLASH ----
    whiteon()
    time.sleep(0.05)
    alloff()
    yellowon()
    time.sleep(0.05)
    alloff()
    time.sleep(0.05)
    whiteon()
    time.sleep(0.05)
    alloff()
    yellowon()
    time.sleep(0.05)
    alloff()
    time.sleep(0.05)
    # ---- BLUE FLASH ----
    blueon()
    time.sleep(0.05)
    alloff()
    time.sleep(0.05)
    blueon()
    time.sleep(0.05)
    alloff()
    time.sleep(0.05)
    blueon()
    time.sleep(0.05)
    alloff()
    time.sleep(0.05)
    blueon()
    time.sleep(0.05)
    alloff()
    time.sleep(0.05)
    # ---- WHITE / YELLOW FLASH ----
    whiteon()
    time.sleep(0.05)
    alloff()
    yellowon()
    time.sleep(0.05)
    alloff()
    time.sleep(0.05)
    whiteon()
    time.sleep(0.05)
    alloff()
    yellowon()
    time.sleep(0.05)
    alloff()
    time.sleep(0.05)

def modetwo():
    # ---- RED FLASH ----
    redon()
    time.sleep(0.05)
    alloff()
    time.sleep(0.05)
    redon()
    time.sleep(0.05)
    alloff()
    time.sleep(0.05)
    redon()
    time.sleep(0.05)
    alloff()
    time.sleep(0.05)
    redon()
    time.sleep(0.05)
    alloff()
    time.sleep(0.05)
    # ---- PAUSE ----
    alloff()
    time.sleep(0.2)
    # ---- BLUE FLASH ----
    blueon()
    time.sleep(0.05)
    alloff()
    time.sleep(0.05)
    blueon()
    time.sleep(0.05)
    alloff()
    time.sleep(0.05)
    blueon()
    time.sleep(0.05)
    alloff()
    time.sleep(0.05)
    blueon()
    time.sleep(0.05)
    alloff()
    time.sleep(0.05)
    # ---- PAUSE ----
    alloff()
    time.sleep(0.2)

def modethree():
    # ---- RED FLASH ----
    redon()
    time.sleep(0.15)
    # ---- PAUSE ----
    alloff()
    time.sleep(0.25)
    # ---- BLUE FLASH ----
    blueon()
    time.sleep(0.15)
    # ---- PAUSE ----
    alloff()
    time.sleep(0.25)

######################### MAIN LOOP ##############################
mode = 0
while True:
    alloff()

    if (mode == 0):
        modeone()
    elif (mode == 1):
        modetwo()
    else:
        modethree()

    if touch.value:
        print("D3 touched! Changing mode")
        mode = (mode+1)
    if (mode > 2):
        mode = 0

    print("Loop Complete")

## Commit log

2019-03-23 Kicad Library Updates
    [3000_Society_Badge.sch]
2019-03-23 Started EDA project over using KiCad 5.1
    [3000_Society_Badge.kicad_pcb, 3000_Society_Badge.sch, 3000_Society_Badge_K5.kicad_pcb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]
2019-03-24 KiCad part schematic and footprint definitions
    [3000_Society_Badge_K5.kicad_pcb, 3000_Society_Badge_K5.sch]
2019-03-24 Graphic export and KiCad import tasks
    [3000_Society_Badge_K5.kicad_pcb, 3000_Society_Badge_K5.sch, 3kbadge-for-export-v4-EdgeCuts.dxf]
2019-03-27 parts customization
    [3000_Society_Badge_K5.kicad_pcb, CP_Radial_D6.3mm_P2.50mm.step, LED_D5.0mm-4_RGB.step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]
2019-03-27 updates to footprints
    [LED_D8.0mm-4-RGB.step]
2019-03-28 3d model updates
    [3000_Society_Badge_K5.kicad_pcb, 3000_Society_Badge_K5.sch]
2019-03-28 Footprint and model cleanup
    [3000_Society_Badge_K5.kicad_pcb, 3000_Society_Badge_K5.sch, LED_D5.0mm-4_RGB_Neo.step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]
2019-03-29 removing footprint cache and adding it to gitignore
2019-03-30 pcb work
    [3000_Society_Badge_K5.kicad_pcb]
2019-03-30 Added Copper Touch Pad to PCB
    [3000_Society_Badge_K5.kicad_pcb]
2019-03-31 Back Silkscreen Work
    [3000_Society_Badge_K5.kicad_pcb]
2019-03-31 Board Layout Updates
    [3000_Society_Badge_K5.kicad_pcb, 3000_Society_Badge_K5.sch]
2019-03-31 Generated gerber files for prototype run.
    [3000_Society_Badge_K5-B_Cu.gbr, 3000_Society_Badge_K5-B_Mask.gbr, 3000_Society_Badge_K5-B_SilkS.gbr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]
2019-04-09 started corrections from prototype
    [3000_Society_Badge_K5.kicad_pcb]
2019-04-09 corrections from 1st prototype run
    [3000_Society_Badge_K5-B_Cu.gbr, 3000_Society_Badge_K5-B_Mask.gbr, 3000_Society_Badge_K5-B_SilkS.gbr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]
2019-04-19 added a new led mode and cleaned up code
2019-07-19 Assembly details and pics
2019-07-19 Correction to assembly instructions
2019-07-19 Formatting of assembly page
2019-07-19 Maybe Ill eventually make the assembly page look good
2019-07-19 Ug assembly again
2019-07-19 assembly page old school

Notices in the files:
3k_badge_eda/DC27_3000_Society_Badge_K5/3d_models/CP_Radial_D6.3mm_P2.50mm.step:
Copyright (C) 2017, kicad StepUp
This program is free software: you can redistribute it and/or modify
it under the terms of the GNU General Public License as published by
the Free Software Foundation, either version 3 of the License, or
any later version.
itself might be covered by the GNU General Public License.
